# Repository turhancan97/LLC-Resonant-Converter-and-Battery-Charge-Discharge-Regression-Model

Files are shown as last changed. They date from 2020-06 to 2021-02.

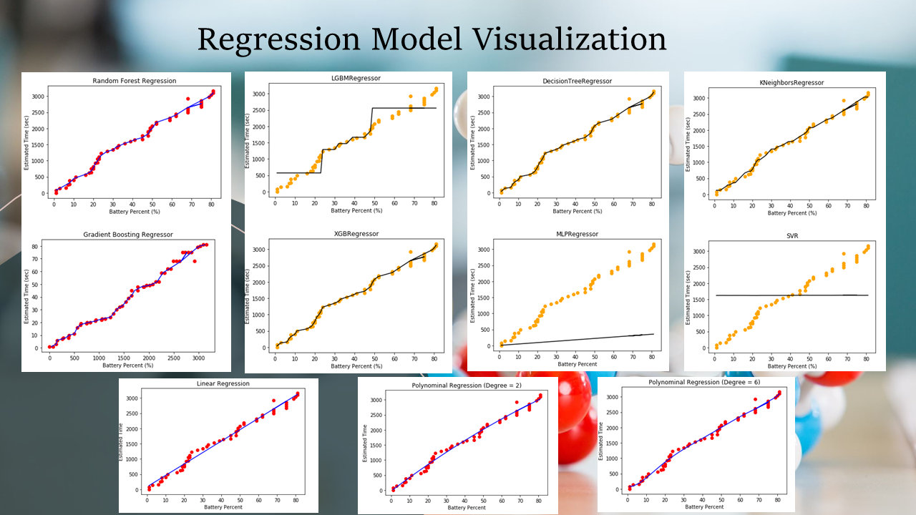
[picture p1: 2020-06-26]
Machine Learning Part/Regression Model Visualizations.png

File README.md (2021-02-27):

# High Power Efficiency Design Approach of a LLC Resonant Converter for UPS Battery Charger Application and Battery Charge - Discharge Regression Model
## Turhan Can Kargın BACHELOR OF SCIENCE GRADUATION PROJECT

In this project, an optimal design procedure of inductor-inductor-capacitor (LLC) resonant DC-DC converter is developed for uninterruptible power supply (UPS) battery charge applications based on high power efficiency. The LLC resonant converters have many advantages such as high-power efficiency and less switching losses when compared with other converters features. It is also capable of operating in narrow switching frequency where zero voltage switching can be provided. The DC-DC converter with 400V input and 48V/3.1A output has been selected as an experimental setup. In order to reach optimal design of LLC resonant converter and required output values, switching frequency might be determined as above of resonance frequency, based on theoretical calculations and Power Electronics Simulation package program. The obtained maximum power efficiency with the proposed method was measured as 95.22%. Besides, charge-discharge models of the battery were obtained from the battery data obtained via deriving regression models with machine learning algorithms where battery electrical energy consumptions, battery status, and temperature data can be analyzed. R^2 score and root mean square error tests are performed for ten different regression models. Random forest regression is determined as the best model among regression models for the obtained data set. 

Keywords: Energy; UPS battery charge; LLC resonant converter; regression models

Video -> https://www.youtube.com/watch?v=KwHaqaDpCxg&t=8s

### Simulation
Simulation_Image

### Schematic
Schematic_Image

### PCB
LLC_Demo_Board_Top

### Model Comparison
Model Comparison

### Random Forest Score After Optimization Code
Random_Forest_skorlar

### Regression Models Visualization
Regression Model Visualizations

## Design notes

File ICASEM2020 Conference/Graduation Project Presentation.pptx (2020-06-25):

## High Power Efficiency Design Approach of a LLC Resonant Converter for UPS Battery Charger Application and Battery Charge-Discharge Regression Model

Graduatıon project
Turhan Can KArgın

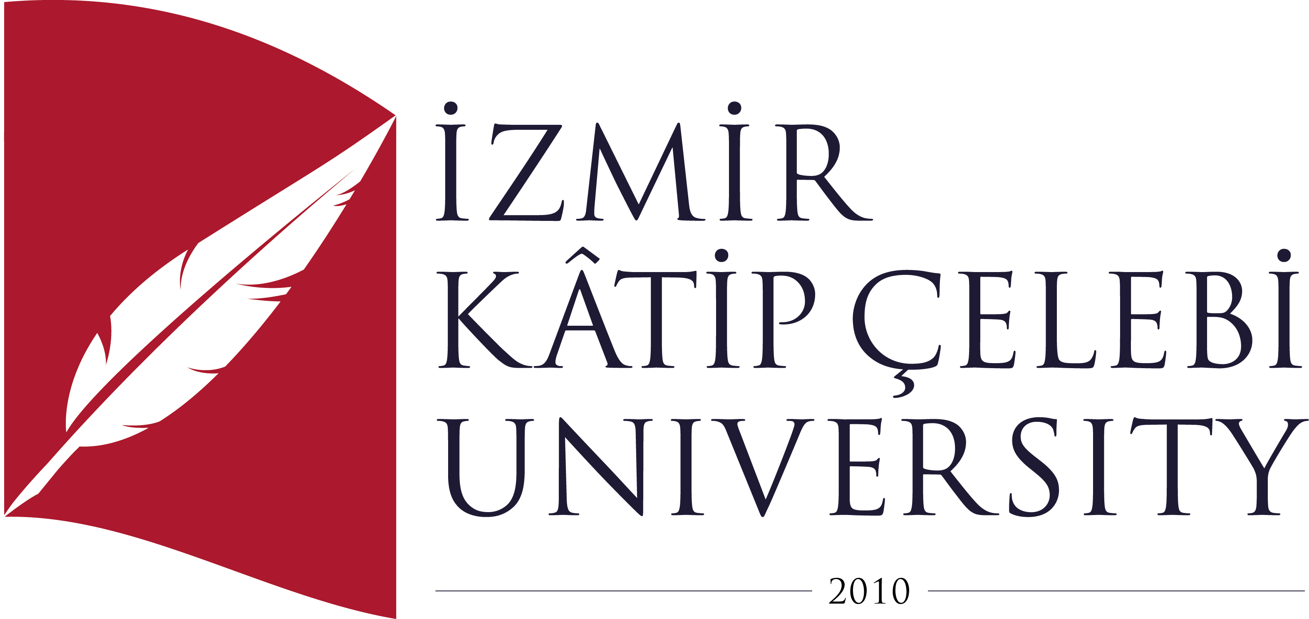
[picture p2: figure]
İzmir Kâtip Çelebi Üniversitesi - Vikipedi

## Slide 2

- SUPERVISOR: Assoc. Prof. Savaş ŞAHİN
- CO-SUPERVISOR: Fırat DEVECİ – TESCOM Elektronik A.Ş.
- This work is supported by the Scientific and Technical Research Council of Turkey (TUBITAK) under 2209B-Bachelor Final Thesis Focused on Industry Program with Project number 1139B411900874.
- This work is presented in 2nd International Conference of Applied Sciences, Engineering and Mathematics (ICASEM 2020).

High Power Efficiency Design Approach of a LLC Resonant Converter for UPS Battery Charger Application and Battery Charge-Discharge Regression Model

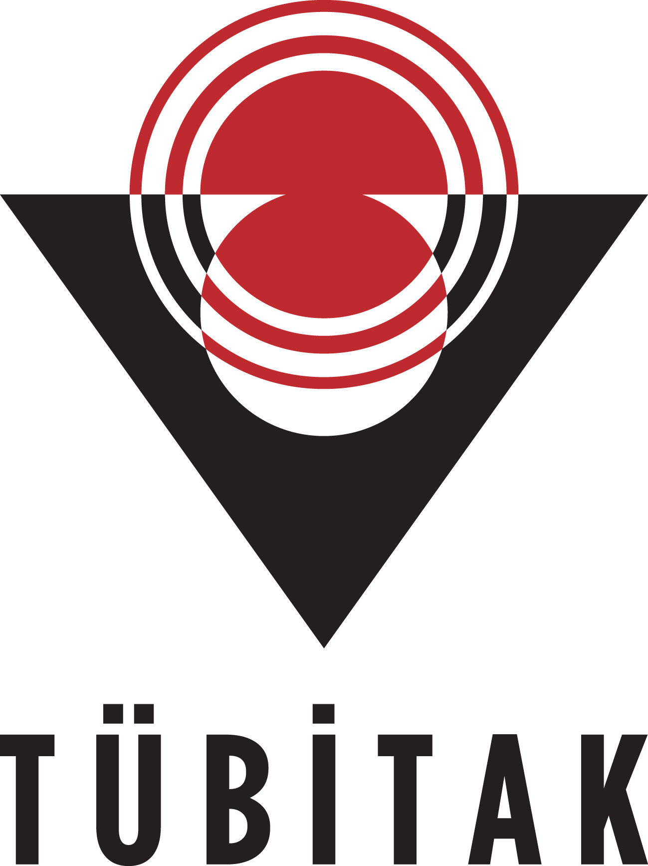
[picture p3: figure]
Tanıtım Materyalleri | BİLİŞİM ve BİLGİ GÜVENLİĞİ İLERİ ...
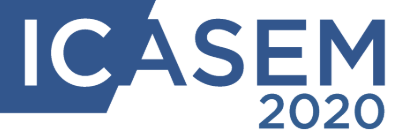
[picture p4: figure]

## Introduction

- This presentation present the analysis and design considerations for a half-bridge LLC resonant DC-DC converter. Using the fundamental approximation, the voltage and current waveforms are analyzed and the gain equations are obtained. Half-bridge LLC resonant converter has 400V input and 48V/3.1A output.The circuit is simulated using PSIM software. In addition, it is presented as secondary output to find the charge-discharge models under varying conditions by deriving the regression models with machine learning algorithms where the battery electricity energy consumption, battery status and temperature data can be analyzed.

## LLC Rezonant Converter

- 1. The advantages of LLC Rezonant Converter
- 2. Why to use as UPS Battery Charger

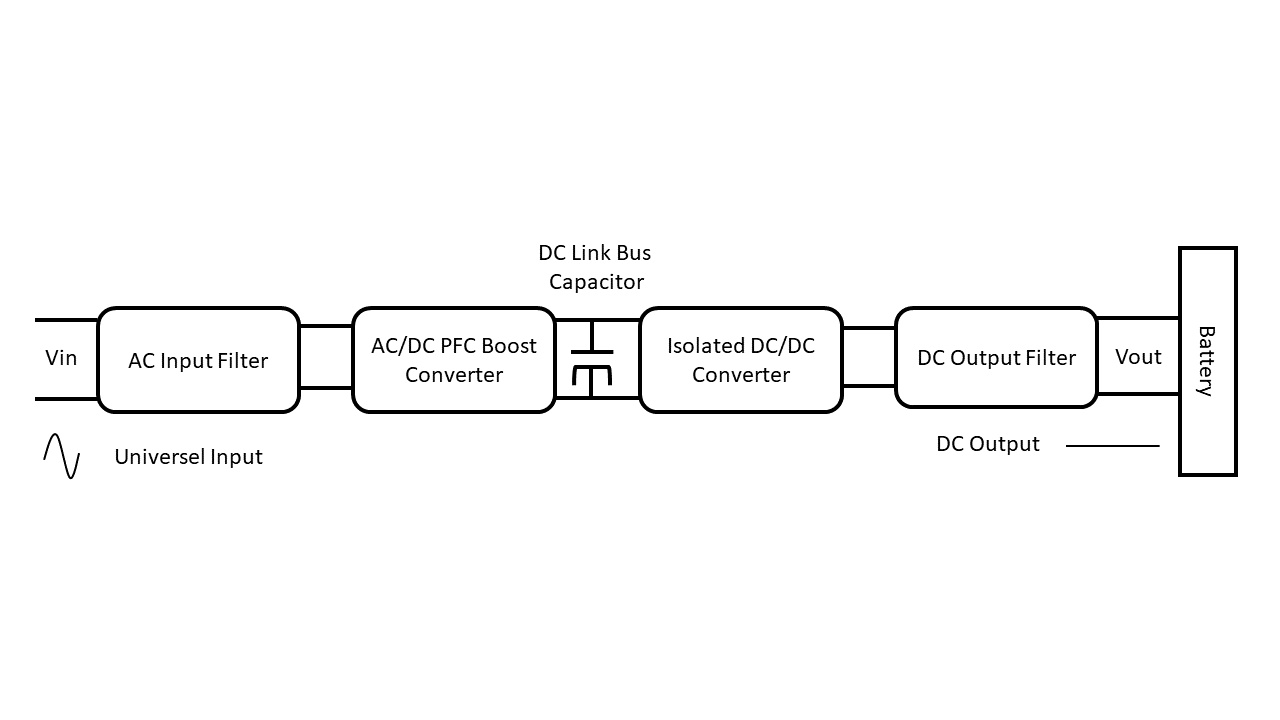
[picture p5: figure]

Block diagram of a universal battery charger

## Circuit Design

  - Define the system specifications and determine the maximum and minimum voltage gains of the resonant network
- P_(in) =(P_(out))/(E_(ff))
- V_(in)^(max) =V_(o.PFC)
- V_(in)^(max) =√(V_(O.PFC)^2 −(2P_(in) T_(HU))/(C_(DL)))
- M^(min) =√(m/(m−1))
- M^(max) = (V_(in)^(max))/(V_(in)^(min))M^(min)

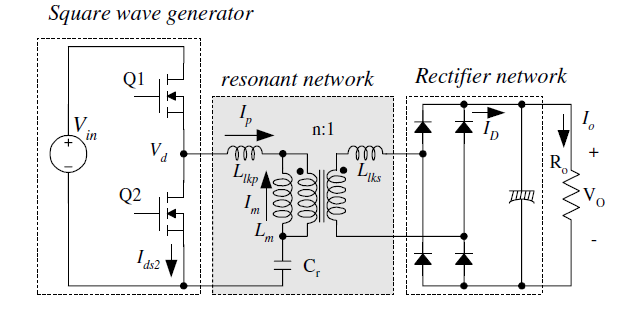
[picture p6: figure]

A schematic of half-bridge LLC resonant converter

## Circuit Design

  - Calculate the Equivalent Load Resistance and Design the resonant network
- R_(ac) = (8n^2)/(π^2)(V_0^2)/(P_0)
- C_r =1/(2πQ.f_o .R_(ac))
- L_r =1/(4π^2 f_o^2 C_r)
- L_p =m.L_r

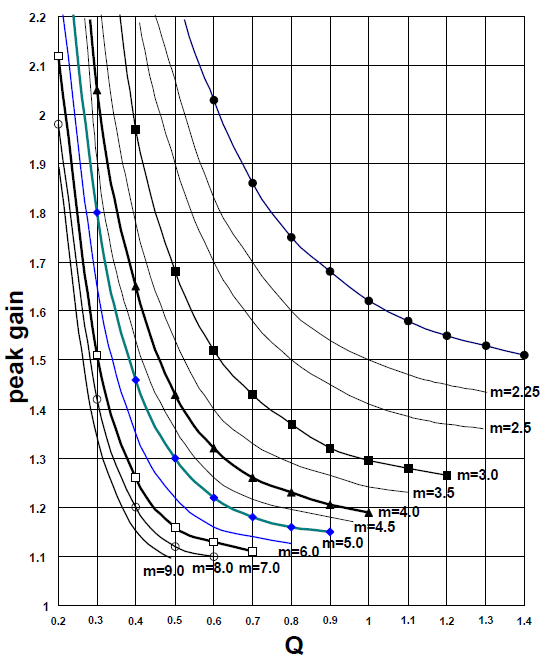
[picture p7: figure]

Peak Gain (Attainable Maximum Gain) vs. Q for Different m Values

With m value chosen in previous slide, read proper Q value from the peak gain curves in Figure that allows enough peak gain. Considering the load transient and stable zero-voltages-witching (ZVS) operation, 10~20% margin should be introduced on the maximum gain when determining the peak gain.

## Circuit Design

  - Design the transformer and select the resonant capacitor
N_p^(min) =(n(V_o +V_F ))/(2f_s^(min) ∆B.1,12.A_e)

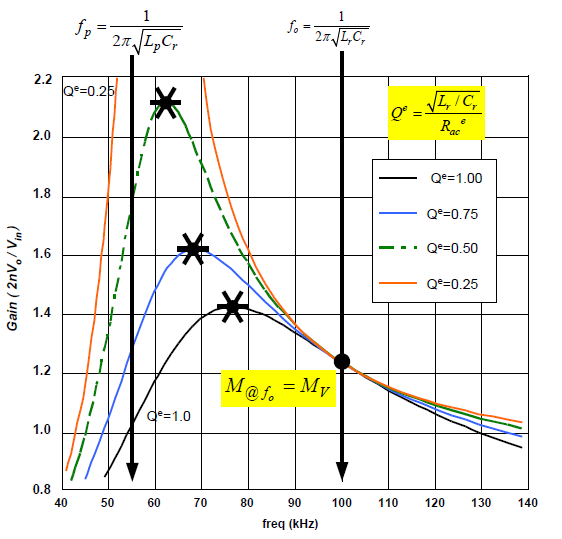
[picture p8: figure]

Typical Gain Curves of LLC Resonant Converter

From the gain curve of Figure, the minimum switching frequency will be obtained

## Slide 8

Design Specification

Define Ratio ‘n’

Design results are calculated as;
E_(ff) = %96 V_(in)^(min) = 363.276V k = 9.4
P_(in) = 150 W V_(in)^(max) = 400 V
P_(out) = 148.8W M^(min) = 1.1066
n=4.375 M^(max) = 1.22
R_(ac) = 251.9 Ω C_r = 19.03 nF
L_r = 110 uH L_p = 600 uH
L_(lkp) = 57.78 uH L_(lks) = 2.879 uF
L_m = 542.2177 uH N_p = 36
N_s = 8 I _(Cr)^(RMS) = 1.044 A
V _(Cr)^(Max) = 495 V Q = 0.302

Define Value of Mmax-Mmin

Select Value of k and Q

Check M, k and Q Graph

Are the values of M, k and Q is in the Limit.(ZVS)

NO

YES

Calculate ‘Rac’

Therotical calculation results

Calculate ‘Cr’

Circuit design results

## Simulation Results

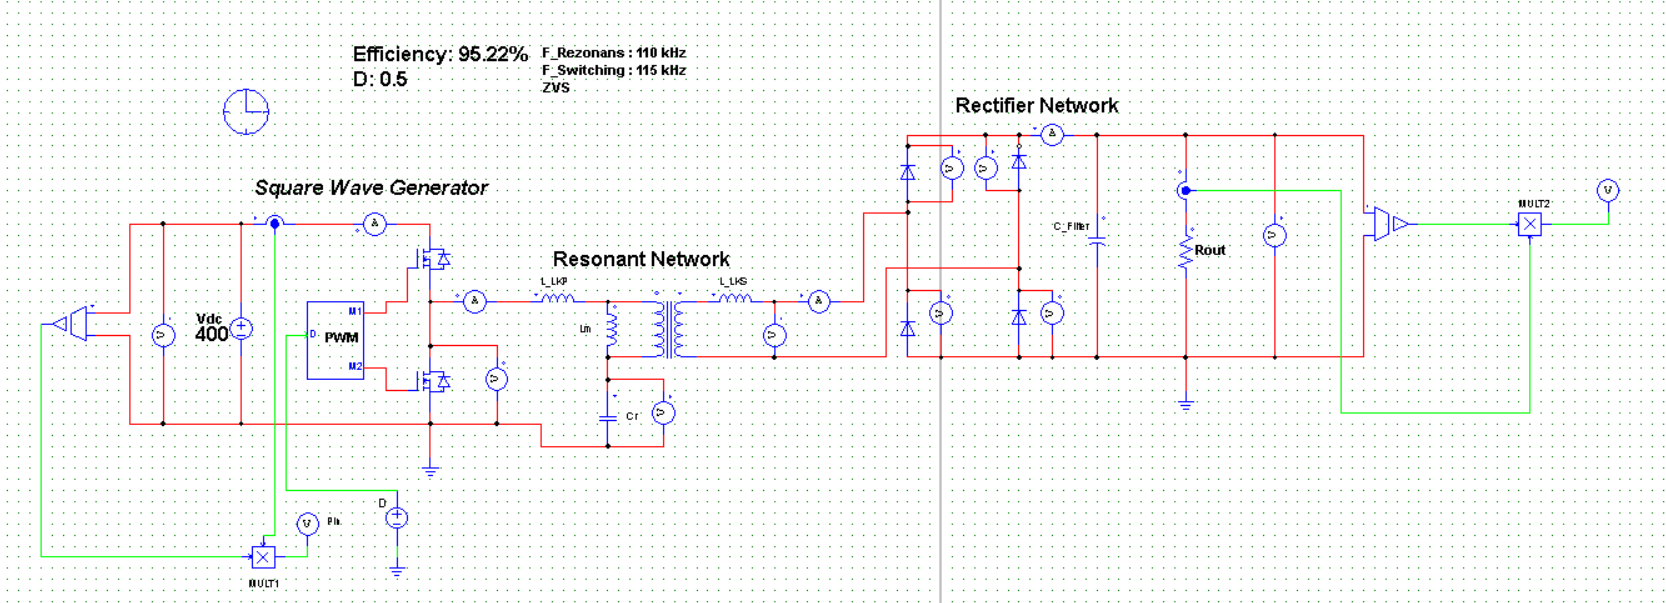
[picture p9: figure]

## Simulation Results

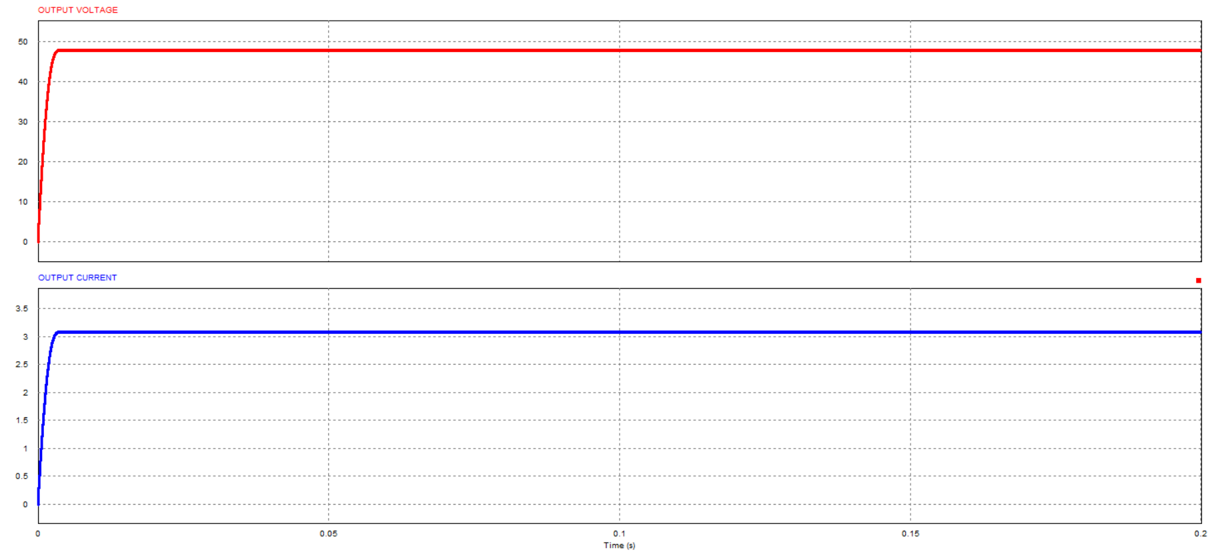
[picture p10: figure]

Output Voltage (V) and output current (A) of the LLC Resonant Converter

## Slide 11

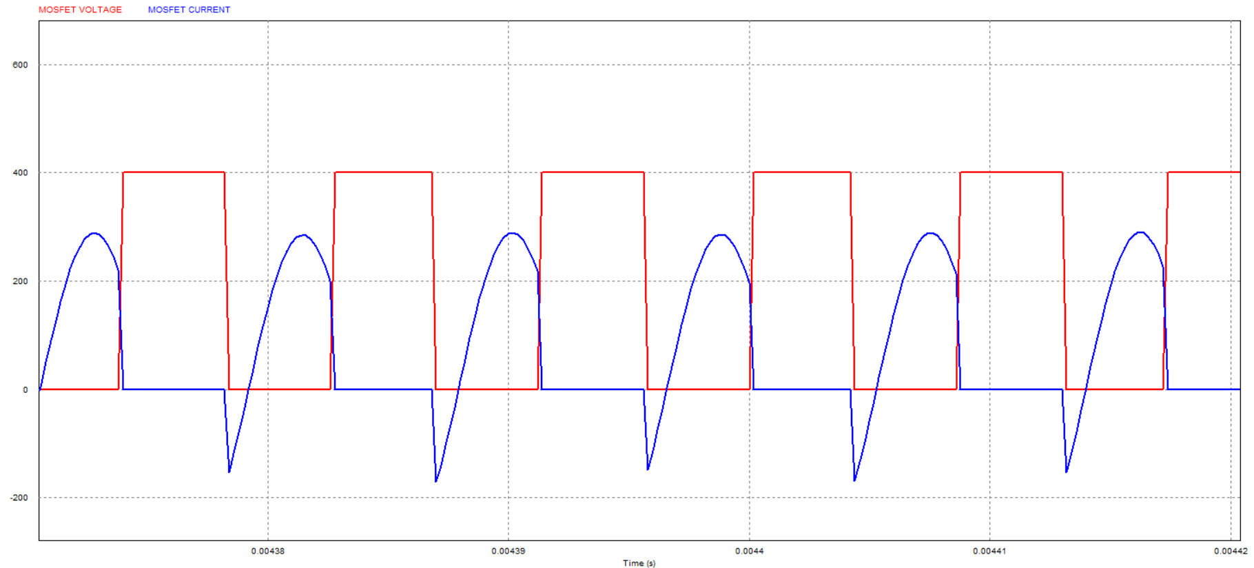
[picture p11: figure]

E_(ff) = %9 5.22

MOSFET voltage (V) and current (A) achieving soft switching

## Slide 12

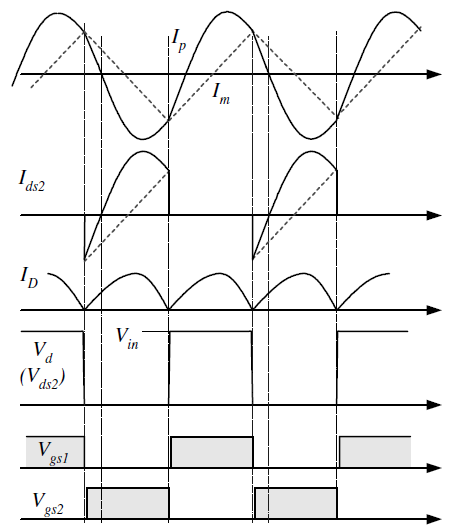
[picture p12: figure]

Typical Voltage (V) and current (A) waveforms of half-bridge LLC resonant converter

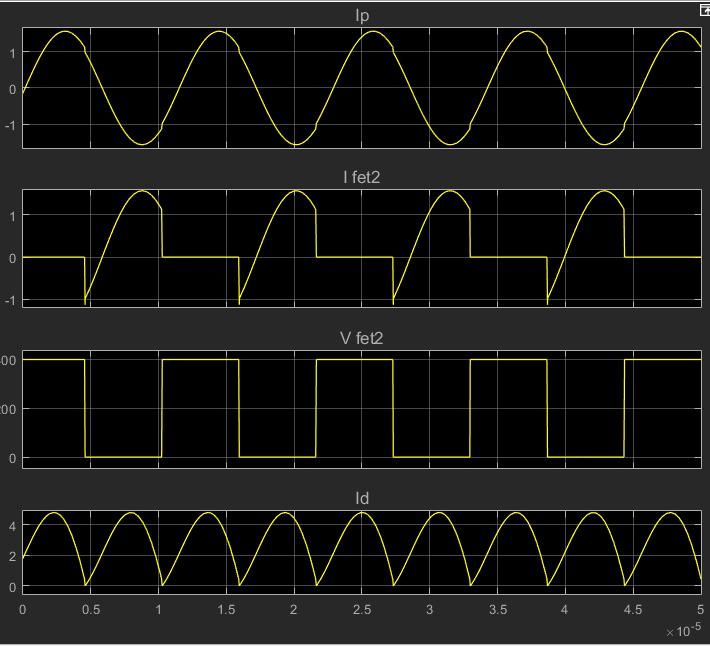
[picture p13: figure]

Simulation Voltage (V) and current (A) waveforms of resonant converter

## PCB Design

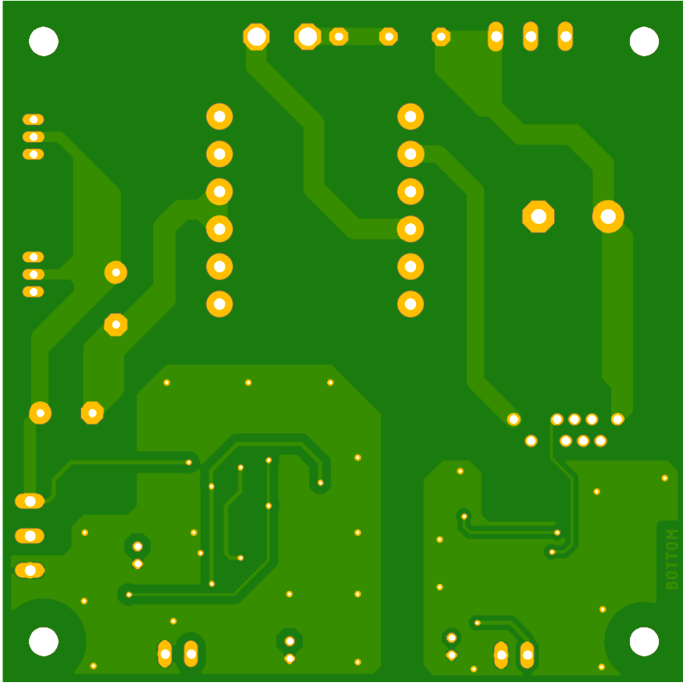
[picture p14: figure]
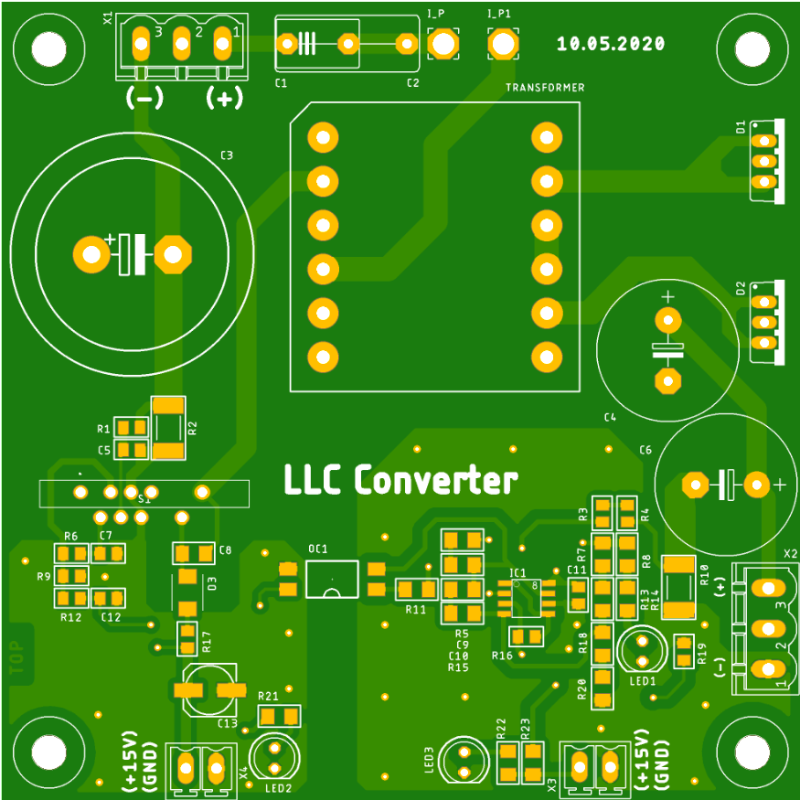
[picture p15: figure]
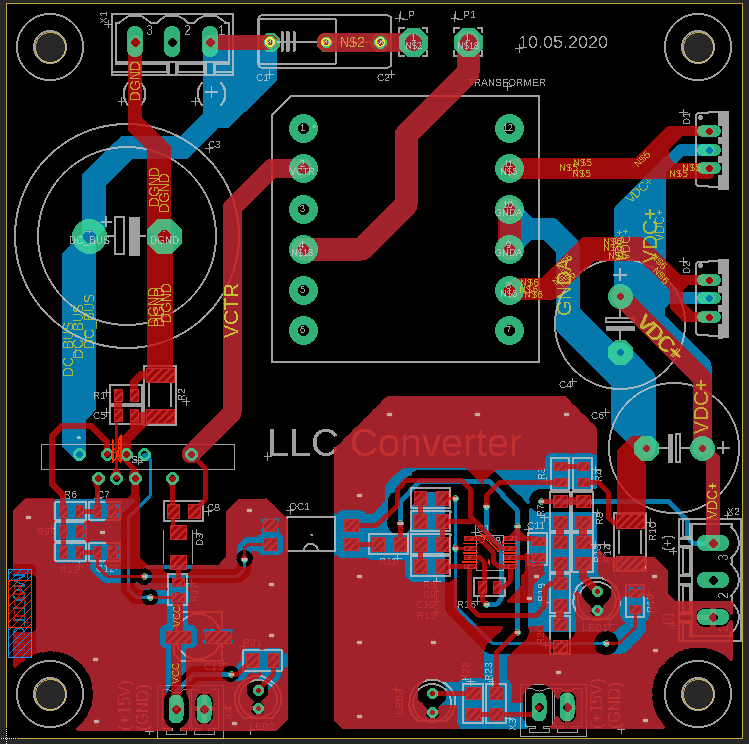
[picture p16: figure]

## Regression Models with Machine Learning

Results Regression Models | Root Mean Square Error | R^2 Score
SVR | 1057.0299 | 0.0008
Linear Regression | 77.2032 | 0.9946
LGBM Regressor | 465.0893 | 0.8065
XGB Regressor | 93.0894 | 0.9922
Gradient Boosting Regressor | 70.8098 | 0.9955
Random Forest Regressor | 67.843 | 0.9959
Decision Tree Regressor | 128.161 | 0.9853
MLP Regressor | 994.0306 | 0.1164
K-Neighbours Regressor Polynomial Regressor | 104.8204 70.5056 | 0.9901 0.9956

Regression model comparison using Python

## Regression Models with Machine Learning

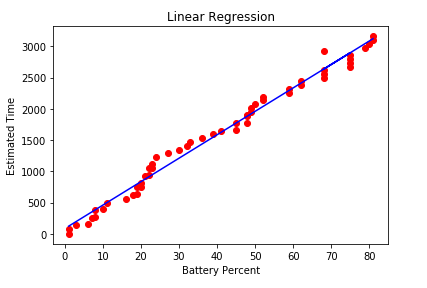
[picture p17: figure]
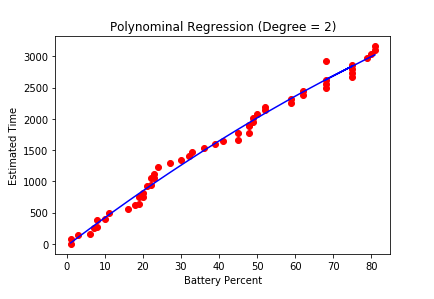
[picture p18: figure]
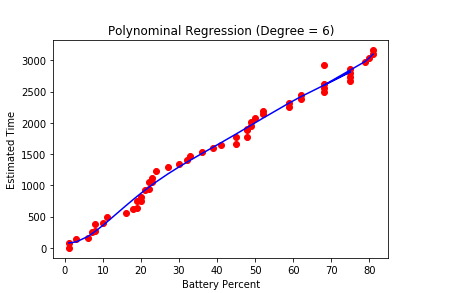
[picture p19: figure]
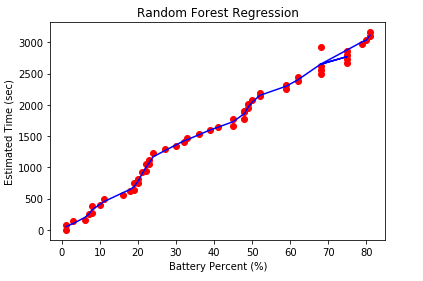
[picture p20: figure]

Visualization of battery discharge regression models

## Thank You

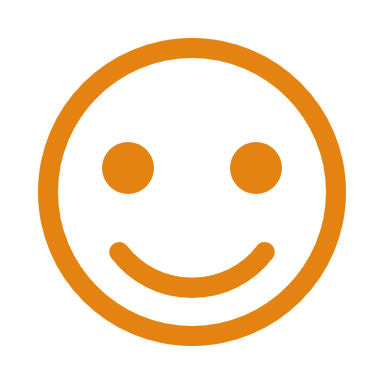
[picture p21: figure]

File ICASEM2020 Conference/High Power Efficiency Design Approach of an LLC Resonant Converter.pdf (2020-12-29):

INTERNATIONAL CONFERENCE OF APPLIED

SCIENCES, ENGINEERING AND MATHEMATICS

HIGH POWER EFFICIENCY DESIGN APPROACH OF AN LLC RESONANT CONVERTER FOR UPS BATTERY CHARGER APPLICATION AND BATTERY CHARGE-DISCHARGE REGRESSION MODEL

Turhan Can Kargın¹*

, Fırat Deveci²

, Savaş Şahin¹

1Department of Electrical and Electronics Engineering, Izmir Katip Celebi University, Izmir, Turkey
2Department of Research and Development, Tescom Elektronik A.Ş., Izmir, Turkey

Abstract - In this study, design procedure of inductor-inductor-capacitor (LLC) resonant DC-DC converter is developed for uninterruptible power supply battery charge applications based on high power efficiency. The LLC resonant converters have many advantages such as high-power efficiency and less switching losses when compared with other converters features. It is also capable of operating in narrow switching frequency where zero voltage switching can be provided. The DC-DC converter with 400V input and 48V/3.1A output has been selected as an experimental setup. In order to reach desired design of LLC resonant converter and required output values, switching frequency might be determined as above of resonance frequency via Power Electronics Simulation package program. The obtained maximum power efficiency was measured as 95.22%. Besides, charge-discharge models of the battery were obtained from the battery data obtained via deriving regression models with machine learning algorithms where battery electrical energy consumptions, battery status, and temperature data can be analyzed. R

2 and root mean square error scores are performed for different regression models. Random forest regression is determined as the best model among regression models for the obtained data set.

Key words: Energy, UPS battery charge, LLC resonant converter, machine learning, regression models

1. INTRODUCTION

Uninterruptible power supplies (UPS) are devices that provide emergency electrical power to a connected device when the input power source fails [1]. Such devices are widely used in important sectors such as industry, healthcare, and military [2-4]. The batteries used in UPS must have satisfied the features such as smooth and quick charging, high power density, high efficiency. The charging of the batteries becomes very complicated due to the high voltages and currents involved in the system and the sophisticated charging algorithms [5]. The most commonly used battery charging architecture is shown in Fig.1. It consists of mainly two stages, namely power factor correction PFC stage and DC-DC converter

2 | TURHAN CAN KARGIN, FIRAT DEVECI, SAVAŞ ŞAHIN

stage. The power factor correction stage is a continuous conduction mode of boost topology [6]. DC-DC converter plays an important role in battery charger by regulating the output current and voltage.

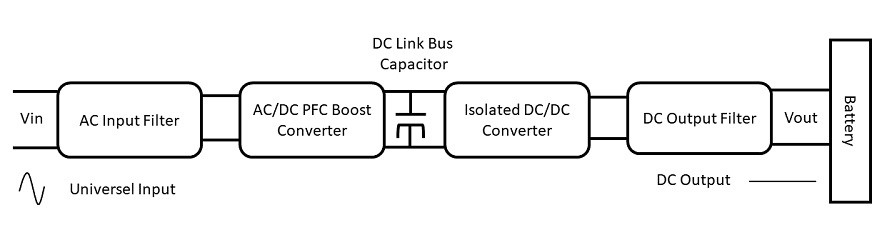
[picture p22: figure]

Fig. 1 Block diagram of a universal battery charger

It has been observed that LLC resonant converters are generally used in electrical vehicles battery charger applications because high power density and high efficiency battery chargers should be designed to have less volume and cost of electrical vehicles [7-9]. In this study, design procedure of LLC resonant converter for UPS battery charger applications based on high efficiency and battery charge-discharge regression model is aimed. In the design procedure, 4x12V UPS battery is taken into consideration. Thus, LLC resonant converter should be regulated the output voltage in a wide voltage range with different load conditions according to typical charging profile of battery. For the design procedure, basic operation characteristics of LLC resonant converter is defined, and operation regions are discussed in terms of high efficiency. To achieve high efficiency, all essential parasitic elements, including junction capacitances of all semiconductor devices and the leakage inductance and magnetizing inductance of the transformer should be utilized to achieve Zero Voltage Switching (ZVS). ZVS switching topology typically use resonance techniques to force the voltage or current in a semiconductor switch to zero, resulting to the elimination or reduction of the switching losses [10]. It is basically soft switching technique. The operation regions of LLC resonant converter are discussed to regulate wide output voltage range. Therefore, the purpose of the study is designing an LLC resonant converter that will have 48V/3.1A output values to charge 4 x 12V / 30Ah batteries. The circuit is simulated using Power Electronic Simulation Software (PSIM). In addition, it is presented as secondary output to find the charge-discharge models under varying conditions by deriving the regression models with machine learning algorithms where the battery electricity energy consumption, battery status and temperature data can be analyzed. Root mean square error (RMSE) and R

2
score tests were used to compare the obtained results.

The remaining sections are as follows; in the second section, circuit design procedure, simulation results and regression models are explained. In the third section, the results from the comparison of model performances with each other is done. In the last section, conclusions and recommendations of the study are presented.

LLC RESONANT CONVERTER FOR UPS BATTERY CHARGER APPLICATION | 3
2. MATERIALS AND METHOD

The half-bridge LLC resonant converter is given in Fig.2. The main parts of this converter are Square wave generator, Resonant network, and Rectifier network.

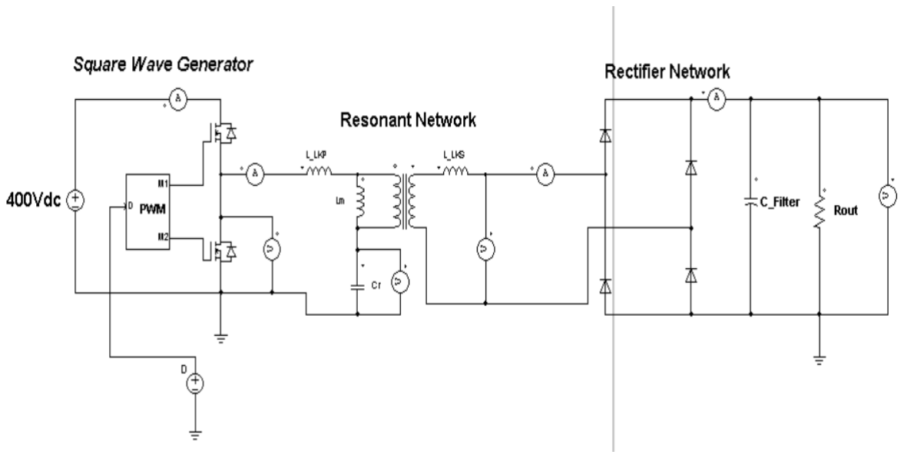
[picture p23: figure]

Fig. 2 The circuit schematic of LLC resonant DC-DC converter

The switching network produces a square wave voltage by alternating 50% duty cycle for each switch. The switching network can be full-bridge or half-bridge type. In this study, it is used as half-bridge type. The resonant network has a resonant capacitor, primary and secondary leakage inductances, and the magnetizing inductance of the transformer. The energy is transferred to the load with the help of transformers when the resonant converter allows the current to circulate. The resonant network filters the higher harmonic currents. Therefore, essentially only sinusoidal current is can flow from the resonance network, although square wave voltage is applied to the resonance network. The rectifier network consists of a filter capacitor and diodes. It produces DC voltage by rectifying the output of the transformer which is a sinusoidal voltage. This network can be full-wave bridge or center-tapped configuration [11].

2.1. Circuit Design Procedure

A dc/dc converter with 148.8W/48V output has been selected as a design for UPS battery charger. The design specifications are as follows; i) Input voltage: 400Vdc (output of PFC stage), ii) Output: 48V/3.1A (148.8W), iii) Holdup time requirement: 20ms (50Hz line freq.), and iv) DC link capacitor of PFC output: 220 µF. The design steps for the half-bridge LLC resonant converter are given below [12]. It is assumed that the efficiency is to be 0.88~0.92 for low voltage output and 0.92~0.96 for high voltage output, if its efficiency data are not provided, See Eq. (1).

o
in

ff

P
P
E
= | (1)

Mostly, LLC resonant converter operates around the resonant frequency (fo) in normal operation to attenuate switching frequency variation. The gain at fo is magnetizing inductance divided by primary side leakage inductance (k = Lm/Llkp). Therefore, the value of k should be chosen to obtain the minimum gain. Mostly, k is chosen 5~10. See Eq. (2) and Eq. (3).

1

2

min | RO | m | lkp
| max
in | m
V | L | L | k
M
V | L | k
+ | +
= | = | = | (2)

max
max | min in
min
in

V
M | M
V

=
(3)

The ratio (k) between Lm and Llkp is chosen as 9.4. LLC resonant converter contains full-

wave bridge rectifier for the rectifier network. The transformer turns ratio should be

determined for full-wave bridge rectifier. See Eq. (4).

2( 2 )

Max
p | in | min
s | o | f
N | V
n | M
N | V | V
= | =
+

(4)

Where
Vf

= 0.7V. Transformer turns ratio obtained from Eq. (4), the equivalent load

resistance is should be obtained. See Eq. (5).

2 2

2

8 | o
ac | ff o

n V
R | E
π P

=
(5)

The resonant network parameters should be determined to achieve soft switching. See Eq. (6), Eq. (7), and Eq. (8).

( | )
( | )
( | )

2
1
1
2 | 1 p | m | lkp | lkp | r

k
L | L | L | k | L | L
k

+
= | + | =
+
+ | =
(6)

( )

2

1
/ / | 1
1 | 2
r | lkp | m | lkp | lkp
o | r

k
L | L | L | L | L
k | π f | C
= | + | = | + | =
+
æ | ö ç | ÷ è | ø
(7)

1

2

r
o ac

C
πQ f R

=
- ·

(8)

The calculated parameters and magnetic component values for simulation are summarized in Table 1.

Table 1. Values used for simulation

Parameters | Values
E ff | %96
P in | 155 W
P out | 148.8 W
N | 4.375
R ac | 251.9 ohm
L r | 110 uH
L lkp | 57.78 uH
L lks | 2.879 uH
L m | 542.2177 uH
C r | 19.03 nF
L p | 600 uH
M min | 1.1066
M max | 1.22
Np : Ns | 36 : 8
Q | 0.302
K | 9.4
2.2. Simulation Results

LLC Resonant topology was built in PSIM software. The duty cycle is 0.5 and resonant frequency is 110 kHz. In order to reach desired design of LLC resonant converter and required output values, switching frequency was determined as above of resonance frequency, based on theoretical calculations and PSIM Simulation software. Therefore, the switching frequency is 115 kHz. Obtained efficiency is 95.22% and that zero voltage switching has been achieved as shown in Fig.3. The intersection area between voltage and current of MOSFET is very less.

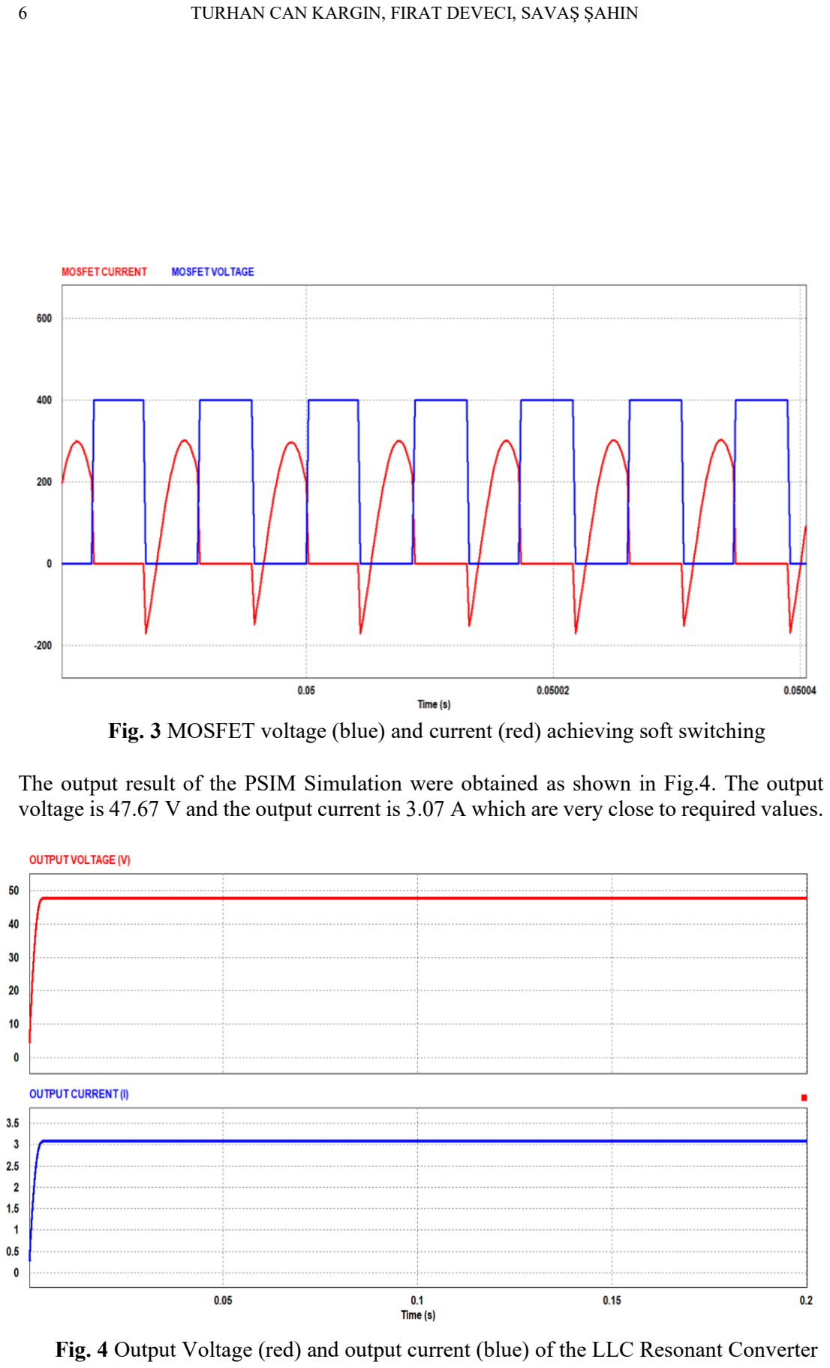
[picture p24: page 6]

Fig. 3 MOSFET voltage (blue) and current (red) achieving soft switching

The output result of the PSIM Simulation were obtained as shown in Fig.4. The output voltage is 47.67 V and the output current is 3.07 A which are very close to required values.

Fig. 4 Output Voltage (red) and output current (blue) of the LLC Resonant Converter

2.3. Regression Models

Regression analysis is a process of statistical methods which is used to estimate relationships between dependent and independent variables. The purpose of machine learning algorithms is learning to recognize the pattern with several different methods. For example, some of them are decision tree, linear regression, support vector machines, artificial neural networks, and k-nearest neighbor. Machine learning algorithms are divided into two groups: supervised learning and unsupervised learning. Regression models are in the group of supervised learning [13]. In this study, it is aimed to provide battery charge-discharge regression model to predict how long a battery with a known charge rate can be discharged according to the load and its medium temperature.by using machine learning algorithms.

3. RESULT AND DISCUSSION

Charge-discharge models of the battery is made by deriving regression models with machine learning algorithms. The data set is obtained from the 10kVA UPS produced by TESCOM A.Ş [14]. There are 4 different variables in the dataset which are discharge current, battery percentage, temperature, and battery usage time. The overall dataset was preprocessed and analyzed thoroughly. Different regression models were used to obtain battery charge-discharge regression models. These are linear, polynomial, light gradient boosting machine (LGBM), extreme gradient boosting (XGB), gradient boosting, random forest, decision tree, and K-neighbors regression. When applying these regression models, battery charge percentage and estimated time variables in the data set were used and to evaluate their performances RMSE and R

2
score are used. See Eq. (9) and See Eq. (10).

RMSE = √
∑ | (yi−ỳi
) m | 2
i=1
| m

(9)

where yi

is the time variable, ỳi
is the value of the predicted time of the regression model.

R

2 = 1− [
∑ | (yi−ỳi )
m | 2
i=1
∑ | (yi−ỹi
) m | 2
i=1
] | (10)

where yi

is the time variable, ỳi
is the value of the predicted time of the regression model and ỹi
is the is the average value of the time variable.

Finally, random forest regression model has been decided as best model among different regression models as shown in Table 2 where the lowest RMSE value and the R

2
score
value is closest to 1. It is depicted in Fig.5.

Table 2. RMSE and R

2
score values of regression models
Regression Models | RMSE | 2 Score R
Linear Regression | 77.2032 | 0.9946
Polynomial Regression | 70.5056 | 0.9956
LGBM Regression | 465.0893 | 0.8065
XGB Regression | 93.0894 | 0.9922
Gradient Boosting Reg | 70.8098 | 0.9955
Random Forest Regression | 67.843 | 0.9959
Decision Tree Regression | 128.161 | 0.9853
K-Neighbors Regression | 104.8204 | 0.9901

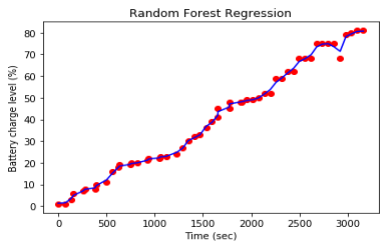
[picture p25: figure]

Fig. 5 Battery charge level versus time

4. CONCLUSION AND RECOMMENDATIONS

LLC resonant DC-DC converter was designed to achieve high efficiency in UPS battery charging applications. LLC resonant DC-DC converter was chosen because the LLC resonant converters have many advantages such as high-power efficiency, less switching losses, and operating in narrow switching frequency where zero voltage switching can be provided when compared with other converters features. Battery charge-discharge regression model is made by using machine learning algorithms, where battery status, battery electrical energy consumption and temperature data were analyzed. Root mean square error and R

2
score tests were performed for different regression models. The tests are generated in Python and the results of them are compared to each other. Random forest regression has been decided as the best regression among regression models for the obtained data set. Finally, it can be predicted how long a battery with a known charge rate can be discharged according to the load and its medium temperature. As a future work of this study could be the hardware implementation for the system and the data can be obtained from the real time application. In addition, more research can be done to make the system perform better.

Acknowledgement: This work is supported by the Scientific and Technical Research Council of Turkey (TUBITAK) under 2209B-Bachelor Final Thesis Focused on Industry Program with Project number 1139B411900874.

REFERENCES

1. A. Von Jouanne, P. Enjeti and D. Lucas, "DSP control of high power UPS systems feeding nonlinear loads," Proceedings of 1995 American Control Conference - ACC'95, Seattle, WA, USA, 1995, pp. 495-499 vol.1, doi: 10.1109/ACC.1995.529299.
2. Gu, B.; Lee, H.; Kang, C.; Sung, D.; Lee, S.; Yun, S.; Park, S.K.; Cho, G.-Y.; Kim, N.; Cha, S.W. Receding Horizon Control of Cooling Systems for Large-Size Uninterruptible Power Supply Based on a Metal-Air Battery System. Energies 2020, 13, 1611.
3. Boris N. Abramovich (2018). Uninterruptible power supply system for mining Industry enterprises. Записки Горного института, 229 (англ.) , 31-40. doi: 10.25515/PMI.2018.1.31
4. L. Zhou and Z. ping Qi, "Modeling and control of a flywheel energy storage system for uninterruptible power supply," 2009 International Conference on Sustainable Power Generation and Supply, Nanjing, 2009, pp. 1-6, doi: 10.1109/SUPERGEN.2009.5348077.
5. F. Musavi, M. Craciun, D. S. Gautam, W. Eberle and W. G. Dunford, "An LLC Resonant DC–DC Converter for Wide Output Voltage Range Battery Charging Applications," in IEEE Transactions on Power Electronics, vol. 28, no. 12, pp. 5437-5445, Dec. 2013, doi: 10.1109/TPEL.2013.2241792.
6. Sri, G., & Subbulekshmi. (2015). LLC Resonant Converter for Battery Charging Application. International Journal of Electrical Engineering, 8(4), 379–388.
7. A. Emadi, Y. J. Lee and K. Rajashekara, "Power Electronics and Motor Drives in Electric, Hybrid Electric, and Plug-In Hybrid Electric Vehicles," in IEEE Transactions on Industrial Electronics, vol. 55, no. 6, pp. 2237-2245, June 2008, doi: 10.1109/TIE.2008.922768.
8. A. Emadi, S. S. Williamson and A. Khaligh, "Power electronics intensive solutions for advanced electric, hybrid electric, and fuel cell vehicular power systems," in IEEE Transactions on Power Electronics, vol. 21, no. 3, pp. 567-577, May 2006, doi: 10.1109/TPEL.2006.872378.
9. D. S. Gautam, F. Musavi, M. Edington, W. Eberle and W. G. Dunford, "An Automotive Onboard 3.3-kW Battery Charger for PHEV Application," in IEEE Transactions on Vehicular Technology, vol. 61, no. 8, pp. 3466-3474, Oct. 2012, doi: 10.1109/TVT.2012.2210259.
10. M. M. Jovanovic, W. A. Tabisz and F. C. Lee, "Zero-voltage-switching technique in high-frequency off-line converters," APEC '88 Third Annual IEEE Applied Power Electronics Conference and Exposition, New Orleans, LA, USA, 1988, pp. 23-32, doi: 10.1109/APEC.1988.10547.
11. Junjun Deng, Siqi Li, Sideng Hu, Mi, C. C., & Ruiqing Ma. (2014). Design Methodology of LLC Resonant Converters for Electric Vehicle Battery Chargers. IEEE Transactions on Vehicular Technology, 63(4), 1581– 1592. https://doi.org/10.1109/tvt.2013.2287379
12. Choi, H. (2007). Design Considerations for an LLC Resonant Converter.
13. Ahmad, T., Chen, H., Huang, R., Yabin, G., Wang, J., Shair, J., Azeem Akram, H. M., Hassnain Mohsan, S. A., & Kazim, M. (2018). Supervised based machine learning models for short, medium and long-term energy prediction in distinct building environment. Energy, 158, 17–32. https://doi.org/10.1016/j.energy.2018.05.169
14. Tescom. (2020), [online] Available: http://www.tescom-ups.com/katalog/TR/TESCOM(TR).pdf

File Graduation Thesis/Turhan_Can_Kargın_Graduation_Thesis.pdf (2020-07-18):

## FACULTY OF ENGINEERING AND ARCHITECTURE

## ELECTRICAL AND ELECTRONICS ENGINEERING

## HIGH POWER EFFICIENCY DESIGN APPROACH OF AN

## LLC RESONANT CONVERTER FOR UPS BATTERY

## CHARGER APPLICATION AND BATTERY CHARGE -

## DISCHARGE REGRESSION MODEL

## GRADUATION PROJECT

## in partial fulfillment of the requirements for the degree of BACHELOR OF SCIENCE

## TURHAN CAN KARGIN

150403005

## SUPERVISOR: ASSOC. PROF. SAVAŞ ŞAHİN

## June 2020

i

HIGH POWER EFFICIENCY DESIGN APPROACH OF AN LLC RESONANT CONVERTER FOR UPS BATTERY CHARGER APPLICATION AND BATTERY CHARGE - DISCHARGE REGRESSION MODEL

A GRADUATION PROJECT

by

TURHAN CAN KARGIN

submitted to the ELECTRICAL AND ELECTRONICS ENGINEERING of

İZMİR KÂTİP ÇELEBİ UNIVERSITY

Approved by:

PROF. DR. ADNAN KAYA

(Signature)

Member Name (Signature) | Member Name (Signature)
Member Name (Signature) | Member Name (Signature)

JUNE 2020

ii

ABSTRACT

In this thesis, an optimal design procedure of inductor-inductor-capacitor (LLC) resonant

DC-DC converter is developed for uninterruptible power supply (UPS) battery charge

applications based on high power efficiency. The LLC resonant converters have many

advantages such as high-power efficiency and less switching losses when compared with

other converters features. It is also capable of operating in narrow switching frequency where

zero voltage switching can be provided. The DC-DC converter with 400V input and

48V/3.1A output has been selected as an experimental setup. In order to reach optimal design

of LLC resonant converter and required output values, switching frequency might be

determined as above of resonance frequency, based on theoretical calculations and Power

Electronics Simulation package program. The obtained maximum power efficiency with the

proposed method was measured as 95.22%. Besides, charge-discharge models of the battery

were obtained from the battery data obtained via deriving regression models with machine

learning algorithms where battery electrical energy consumptions, battery status, and

temperature data can be analyzed. R

2
score and root mean square error tests are performed

for ten different regression models. Random forest regression is determined as the best model

among regression models for the obtained data set.

Keywords: Energy; UPS battery charge; LLC resonant converter; regression models

iii

ÖZET

Bu tezde, yüksek güç verimliliğine dayanan kesintisiz güç kaynağı (KGK) akü şarj

uygulamaları için indüktör-indüktör-kapasitör (LLC) rezonans DA-DA dönüştürücünün

optimal tasarım prosedürü geliştirilmiştir. LLC rezonans dönüştürücülerinin yüksek güç

verimliliği ve diğer dönüştürücülerin özellikleriyle karşılaştırıldığında daha az anahtarlama

kaybı gibi birçok avantajı vardır. Ayrıca sıfır voltaj anahtarlamanın sağlanabildiği dar

anahtarlama frekansında da çalışabilir. 400V giriş ve 48V / 3.1A çıkışlı DA-DA dönüştürücü,

deneysel kurulum olarak seçilmiştir. LLC rezonans dönüştürücüsünün optimum tasarımına ve

gerekli çıkış değerlerine ulaşmak için, anahtarlama frekansı teorik hesaplamalara ve Güç

elektroniği benzetim çalışmaları paket programına dayanarak rezonans frekansının yukarısında olduğu belirlenmiştir. Önerilen yöntemle elde edilen maksimum güç verimliliği

95.22% olarak ölçülmüştür. Ayrıca, akü şarj-deşarj modelleri, akü elektrik enerjisi

tüketiminin, akü durumunun ve sıcaklık verilerinin analiz edilebildiği makine öğrenme

algoritmaları ile regresyon modelleri türetilerek elde edilen akü verilerinden elde edilmiştir.

On farklı regresyon modeli için R

2 ve hata kareler ortalamasının karesi testi yapılmıştır.

Random Forest regresyonu, elde edilen veri seti için regresyon modelleri arasında en iyi

model olarak belirlenmiştir.

Anahtar Kelimeler: Enerji; KGK akü şarjı; LLC rezonans dönüştürücü; regresyon modelleri

iv

ACKNOWLEDGMENTS

This work is supported by the Scientific and Technical Research Council of Turkey

(TUBITAK) under 2209B-Bachelor Final Thesis Focused on Industry Program with Project

number 1139B411900874.

This work is presented in 2nd International Conference of Applied Sciences, Engineering and

Mathematics (ICASEM 2020).

I would like to express my special thanks to my advisor Assoc. Prof. Savaş ŞAHİN for his

patience, motivation and continuous support. My sincere thanks also goes to Mr. Fırat

DEVECI for his guidance and helping me with every step of the project.

Finally, I would like to thank my family and friends for their endless support.

v

TABLE OF CONTENTS

vi

LIST OF TABLES

Table 3-1 Root Mean Square Error and R

vii

LIST OF FIGURES

Figure 3-5 Typical voltage and current waveforms of half-bridge LLC resonant converter ...15

Figure 3-8 Output Voltage (red) and output current (blue) of the LLC Resonant Converter ..16

Figure 3-15 Typical dc voltage gain characteristic of LLC resonant converter as function of

viii

Figure 3-30 (a) Graph of Linear Regression Model, (b) Graph of Polynomial Regression

ix

ACRONYMS

LLC Inductor-Inductor-Capacitor

SRC Series Resonant Converter

DC Direct Current

AC Alternating Current

PFC Power Factor Correction

UPS Uninterruptible Power Supply

IC Integrated Circuit

ZVS Zero Voltage Switching

PCB Printed Circuit Board

SMPS Switch Mode Power Supply

CV Constant Voltage

CC Constant Current

EMI Electromagnetic Interference

LGBM Light Gradient Boosting Machine

XGB eXtreme Gradient Boosting

MLP Multilayer Perceptron

ANN Artificial Neural Network (https://en.wikipedia.org/wiki/Artificial_neural_network)

RMSE Root Mean Square Error

### 1. INTRODUCTION

The growing demand for higher power density and low profile in power converter designs

has forced designers to increase switching frequencies. Operation at higher frequencies

considerably reduces the size of passive components such as transformers and filters.

However, switching losses have been an obstacle to high frequency operation. In order to

reduce switching losses, allowing high frequency operation, resonant switching techniques

have been developed. These techniques process power in a sinusoidal manner and the

switching devices are softly commutated. Therefore, the switching losses and noise can be

dramatically reduced. Conventional resonant converters use an inductor in series with a

capacitor as a resonant network. Two basic configurations are possible for the load

connection: series connection and parallel connections [1]. See Figure 1.1.


Figure 1-1 Half-bridge series and parallel resonant converters [1]

These two different resonant converters have some limitations. For SRC, the rectifier-load

network is placed in series with the L-C resonant network [2-4]. From this configuration, the

resonant network and the load act as a voltage divider. By changing the frequency of driving

voltage Vd, the impedance of the resonant network changes. The input voltage will be split

between this impedance and the reflected load. Since it is a voltage divider, the DC gain of an

SRC is always lower than 1. At light load condition, the impedance of the load will be very

large compared to the impedance of the resonant network; all the input voltage will be

imposed on the load. This makes it difficult to regulate the output at light load. Theoretically,

frequency should be infinite to regulate the output at no load. For parallel resonant converter,

the rectifier-load network is placed in parallel with the resonant capacitor as depicted [5-7].

Since the load is connected in parallel with the resonant network, there inevitably exists large

amount of circulating current. This makes it difficult to apply parallel resonant topologies in

high power applications. Therefore, in order to solve the limitations of the conventional resonant converters, the LLC resonant converter has been proposed. The LLC-type resonant

converter has many advantages over conventional resonant converters. First, it can regulate

the output over wide line and load variations with a relatively small variation of switching

frequency. Second, it can achieve zero voltage switching (ZVS) over the entire operating

range. Finally, all essential parasitic elements, including junction capacitances of all

semiconductor devices and the leakage inductance and magnetizing inductance of the

transformer, are utilized to achieve ZVS. See Figure 1.2.

Figure 1-2 A schematic of half-bridge LLC resonant converter [1]

Recently, the LLC resonant converter has drawn a lot of attention due to its advantages over

the conventional series resonant converter and parallel resonant converter: narrow frequency

variation over wide load and input variation and Zero Voltage Switching (ZVS) of the

switches for entire load range. The LLC-type resonant converter has many advantages over

conventional resonant converters. First, it can regulate the output over wide line and load

variations with a relatively small variation of switching frequency. Second, it can achieve

zero voltage switching (ZVS) over the entire operating range. Finally, all essential parasitic

elements, including junction capacitances of all semiconductor devices and the leakage

inductance and magnetizing inductance of the transformer, are utilized to achieve ZVS. The

battery used in Uninterruptible Power Supply should be in such a way that it should satisfy

the features such as smooth and quick charging, high power density, high efficiency.

Furthermore, battery technology is improving and as this transition occurs, the charging of

these batteries becomes very complicated due to the high voltages and currents involved in

the system and the sophisticated charging algorithms [8]. The most commonly used battery

charging architecture is shown in figure 3. It consists of mainly two stages, namely power

factor correction PFC stage and DC-DC converter stage. The power factor correction stage is

a continuous conduction mode of boost topology [9]. In this thesis, the main focus is the DC-

DC converter which plays an important role in battery charger by regulating the output

current and voltage. See Figure 1.3.


Figure 1-3 Block diagram of a universal battery charger

In this thesis, an optimal design procedure of inductor-inductor-capacitor (LLC) resonant

converter for UPS battery charger applications based on high efficiency and Battery Charge-

Discharge regression model is proposed. In the design procedure, 4x12V UPS battery is used.

Thus, LLC resonant converter should be regulated the output voltage in a wide voltage range

with different load conditions according to typical charging profile of battery. For the design

procedure, basic operation characteristics of LLC resonant converter is defined, and operation

regions are discussed in terms of high efficiency. The operation regions of LLC resonant

converter are discussed to regulate wide output voltage range. Therefore, the purpose of the

thesis is designing and producing an LLC resonant converter that will have 48V/3.1A output

values to charge 4 x 12V / 30Ah batteries. The circuit is simulated using PSIM software. PCB

design was performed by Eagle Autodesk. In addition, it is presented as secondary output to

find the charge-discharge models under varying conditions by deriving the regression models

with machine learning algorithms where the battery electricity energy consumption, battery

status and temperature data can be analyzed.

### 2. MATERIALS

### 2.1. PSIM Simulation Software

PSIM [10] is an Electronic circuit simulation software package, designed specifically for use

in power electronics and motor drive simulations but can be used to simulate any electronic

circuit. Developed by Powersim, PSIM uses nodal analysis and the trapezoidal rule

integration as the basis of its simulation algorithm. PSIM provides a schematic capture

interface and a waveform viewer Simview. PSIM has several modules that extend its

functionality into specific areas of circuit simulation and design including control theory,

electric motors, photovoltaics and wind turbines. PSIM is used by industry for research and

product development and it is used by educational institutions for research and teaching.

There are modules that enable motor drive simulation, digital control, and the calculation of

thermal losses due to switching and conduction. There is a renewable energy module which

allows for the simulation of photovoltaics (including temperature effects), batteries,

supercapacitor, and wind turbines. See Figure 2.1.

Figure 2-1 PSIM Software interface [10]

### 2.2. MATLAB Simulink

Simulink [11] is a MATLAB-based graphical programming environment for modeling,

simulating, and analyzing multidomain dynamical systems. Its primary interface is a

graphical block diagramming tool and a customizable set of block libraries. It offers tight

integration with the rest of the MATLAB environment and can either drive MATLAB or be

scripted from it. Simulink is widely used in automatic control and digital signal processing

for multidomain simulation and model-based design. See Figure 2.2.


Figure 2-2 MATLAB Simulink interface [11]

### 2.3. EAGLE Autodesk

EAGLE [12] is a scriptable electronic design automation (EDA) application with schematic

capture, printed circuit board (PCB) layout, auto-router and computer-aided manufacturing

(CAM) features. EAGLE stands for Easily Applicable Graphical Layout and is developed by

CadSoft Computer GmbH. EAGLE contains a schematic editor, for designing circuit

diagrams. Schematics are stored in files with .SCH extension, parts are defined in device

libraries with .LBR extension. Parts can be placed on many sheets and connected together

through ports. The PCB layout editor stores board files with the extension .BRD. It allows

back-annotation to the schematic and auto-routing to automatically connect traces based on

the connections defined in the schematic. In this thesis, circuit diagram and PCB designs

implemented on this program. See Figure 2.3.

Figure 2-3 EAGLE Autodesk interface [12]

### 2.4. Python and Spyder

Python [13] is an interpreted, high-level, general-purpose programming language. Python's

design philosophy emphasizes code readability with its notable use of significant whitespace.

Its language constructs and object-oriented approach aims to help programmers write clear,

logical code for small and large-scale projects. Python is dynamically typed and garbage-

collected. It supports multiple programming paradigms, including procedural, object-

oriented, and functional programming. Python is often described as a "batteries included"

language due to its comprehensive standard library.

Spyder [14] is a powerful scientific environment written in Python, for Python, and designed

by and for scientists, engineers, and data analysts. It features a unique combination of the

advanced editing, analysis, debugging and profiling functionality of a comprehensive

development tool with the data exploration, interactive execution, deep inspection, and

beautiful visualization capabilities of a scientific package. Furthermore, Spyder offers built-in

integration with many popular scientific packages, including NumPy, SciPy, Pandas,

IPython, QtConsole, Matplotlib, SymPy, and more. Beyond its many built-in features, Spyder

can be extended even further via third-party plugins. Spyder can also be used as a PyQt5

extension library, allowing you to build upon its functionality and embed its components,

such as the interactive console or advanced editor, in your own software. Python

programming language is used for the analysis of the consumption data. See Figure 2.4.


Figure 2-4 Spyder interface [14]

### 3. METHODS

### 3.1. Circuit Design

A dc/dc converter with 148.8W/48V output has been selected as a design for UPS battery

charger. The design specifications are as follows:

- Input voltage: 400Vdc (output of PFC stage)
- Output: 48V/3.1A (148.8W)
- Holdup time requirement: 20ms (50Hz line freq.)
- DC link capacitor of PFC output: 220 μF

[STEP-1] Define the system specifications

-Estimated efficiency (Eff): The power conversion efficiency must be estimated to calculate

the maximum input power with a given maximum output power. If no reference data is

available, use Eff = 0.88~0.92 for low voltage output applications and Eff = 0.92~0.96 for

high voltage output applications. See Equation 3.1

Pin =

Po

Eff

(3.1)

-Input voltage range (Vin

minand Vin

max) : Typically, it is assumed that the input voltage is

provided from Power Factor Correction (PFC) pre-regulator output. When the input voltage

is supplied from PFC output, the minimum input voltage considering the hold-up time

requirement is given. See Equation 3.2

Vin

min = √VO.PFC
2 −

2PinTHU

CDL

(3.2)

where VO.PFC is the nominal PFC output voltage, THU is a hold up time and CDL is the DC

link bulk capacitor. The maximum input voltage is given. See Equation 3.3

Vin

max = VO.PFC | (3.3)

[STEP-2] Determine the maximum and minimum voltage gains of the resonant network

It is typical to operate the LLC resonant converter around the resonant frequency (fo) in

normal operation to minimize switching frequency variation. When the input voltage is

supplied from the PFC output, the input voltage has the maximum value (nominal PFC output

voltage) in normal operation. Designing the converter to operate at fo for the maximum input

voltage condition, the minimum gain should occur at the resonant frequency (fo). The gain at

fo is a function of the ratio (k=Lm/Llkp) between the magnetizing inductance and primary

side leakage inductance. Thus, the value of k should be chosen to obtain the minimum gain.

While a higher peak gain can be obtained with a small k value, too small k value results in

poor coupling of the transformer and deteriorates the efficiency. It is typical to set k to be

5~10, which results in a gain of 1.1~1.2 at the resonant frequency (fo). With the chosen k

value, the minimum voltage gain for maximum input voltage (Vin

max) is obtained. See

Equation 3.4

Mmin =

VRO

Vin

max

2

=

Lm+Llkp
Lm

=

k+1
k

(3.4)

Then, the maximum voltage gain is given. See Equation 3.5

Mmax =

Vin

max

Vin

min . Mmin | (3.5)

The ratio (k) between Lm and Llkp is chosen as 9.4.

[STEP-3] Determine the transformer turns ratio (n=Np/Ns)

Since the full-wave bridge rectifier is used for the rectifier network, the transformer turns

ratio is given. See Equation 3.6

n =

Np
Ns

=

Vin

Max

2(Vo+2Vf)

Mmin
(3.6)

[STEP-4] Calculate the equivalent load resistance (Rac)

With the transformer turns ratio obtained, the equivalent load resistance is obtained.

See Equation 3.7

Rac =

8n

2
π²

Vo

2

Po

Eff | (3.7)

[STEP-5] Design the resonant network

With k chosen in STEP-2, read proper Q value from the peak gain curves in Figure 8 that

results in enough peak gain. 10~15% margin on the peak gain is typical. Then, the resonant

parameters are obtained. See Equation 3.8

### Lp = Lm + Llkp = (k + 1)Llkp

Lr = Llkp + Lm//Llkp = Llkp (1 +

k
k + 1

)

Cr =

1
2πQ⋅fo⋅Rac

(3.8)

Lr =

1
(2πfo)

2Cr

Lp =

(k+1)

2
(2k+1)

Lr

As calculated in STEP-2, the maximum voltage gain (Mmax) for the minimum input voltage

(Vin

min) is 1.22. With 10% margin, a peak gain of 1.5 is required. k has been chosen as 9.4 in

STEP-2 and Q is obtained as 0.302 from the peak gain curves. By selecting the resonant

frequency as 110kHz.

[STEP-6] Design the transformer

The worst case for the transformer design is the minimum switching frequency condition,

which occurs at the minimum input voltage and full load condition. To obtain the minimum

switching frequency, plot the gain curve using the gain equation and read the minimum

switching frequency. Then, the minimum number of turns for the transformer primary side is

obtained. See Equation 3.9

Np

min =

n(V0+2Vf)
2fs

min∆BAe

(3.9)

where Ae is the cross-sectional area of the transformer core in m2 and ΔB is the maximum

flux density swing in Tesla. If there is no reference data, use ΔB =0.25~0.30 T. Then, choose the proper number of turns for the secondary side that results in primary side turns larger than Np

minas given. See Equation 3.10

### Np = n . Ns > Np

min
(3.10)

Ae = 97.1 mm2 is selected for the transformer. From the gain curve in Figure 9 of the

minimum switching frequency is obtained as 85kHz.

[STEP-7] Select the resonant capacitor

When choosing the resonant capacitor, the current rating should be considered since a

considerable amount of current flows through the capacitor. The RMS current through the

resonant capacitor is given. See Equation 3.11

Icr

Rms ≅ √[
πIo
2√2n

]

2
+ [

n(Vo+2⋅Vr

)
4√2foLm

]

2
(3.11)

Then, the maximum voltage of the resonant capacitor in normal operation is given. See

Equation 3.12. See Figure 3.1.

### Vcr

max ≡

Vin

max

2

+

√2⋅Icr

RMS

2⋅π⋅f0⋅Cr

(3.12)


Figure 3-1 Peak Gain (Attainable Maximum Gain) vs. Q for Different k Values

Figure 3-2 Typical Gain Curves of LLC Resonant Converter

Following flowchart diagram was created for the design procedure and values in were

obtained as the design results. See Figure 3.2, 3.3 and 3.4.

Design Specification; Define Ratio ‘n’; Select Value of k and Q; Define Value of Mmax-Mmin; Check M, k and Q Graph; Are the values of M, k and Q is in the Limit.(ZVS); Calculate ‘Cr’; Calculate ‘Rac’; YES

Figure 3-3 Flowchart diagram for design procedure

Figure 3-4 Circuit design results

### 3.2. Simulation

After finding the theoretical results, the simulation of the converter to compare theoretical

results and simulation results was built. Typical waveforms which it has to be seen on the

simulation program. Ip is primary side leakage inductance current, Im is magnetizing current

Ids2 and Vds2are second MOSFET current and voltage and Id is rectifier side current. As you

see, the square wave generator produces a square wave voltage, Vd by driving switches, Q1

and Q2 with alternating 50% duty cycle for each switch. The square wave generator stage can

be built as a full-bridge or half bridge type. In this thesis it was used as half bridge type. See

Figure 3.5.


Figure 3-5 Typical voltage and current waveforms of half-bridge LLC resonant converter

Firstly, LLC Resonant topology was built in PSIM. The duty cycle is 0.5 and resonant

frequency is 110kHz. In order to reach optimal design of LLC resonant converter and

required output values, switching frequency was determined as above of resonance

frequency, based on theoretical calculations and PSIM Simulation software. Therefore, the

switching frequency is 115kHz. Obtained efficiency is 95.22% and that soft switching has

been achieved. The intersection area between voltage and current of MOSFET is very less.

See Figure 3.6 and 3.7

Figure 3-6 PSIM simulation design of LLC resonant DC-DC converter


Figure 3-7 MOSFET voltage (blue) and current (red) achieving soft switching

The output result of the PSIM Simulation were obtained. The output voltage is 47.67V and

the output current is 3.07A which are very close to required values. Besides, primary side

leakage inductance current, magnetizing current, rectifier side current, and MOSFETs’

voltage waveforms were obtained. Simulation results are like these typical waveforms. See

Figure 3.8, 3.9, 3.10 and 3.11.


Figure 3-8 Output Voltage (red) and output current (blue) of the LLC Resonant Converter

Figure 3-9 Magnetizing (blue) and primary side leakage inductor (red) current

Figure 3-10 Secondary side diode current (A)


Figure 3-11 First and second MOSFET voltage (V)

The RMS current through the resonant capacitor was measured as 1.072A and the maximum

voltage of the resonant capacitor in normal operation was measured as 311.5V. See Figure

3.12.

Figure 3-12 Current (black) and voltage (orange) waveforms of resonant capacitor

After that, the system was created on MATLAB Simulink. The required waveforms are

created on MATLAB Simulink too. See Figure 3.13 and 3.14.

Figure 3-13 MATLAB Simulink design of LLC resonant DC-DC converter

Figure 3-14 MATLAB Simulink design waveforms


Figure 3-15 Typical dc voltage gain characteristic of LLC resonant converter as function of load and normalized switching frequency variation [15].

In this simulations, Region 1 ZVS was decided to operate which means switching frequency

is bigger than resonant frequency. Therefore, switching frequency is selected the as 115kHz

(calculated resonant frequency is 110kHz and Q = 0.302). Typical half-bridge LLC resonant

converter waveforms should is obtained in the simulation program and the simulation results

that are similar to these typical waveforms. Besides, the simulation results of the resonant

capacitor maximum voltage and RMS current to select appropriate resonant capacitor and

according to theoretical calculation, results are very similar which means theoretical

calculations correspond to simulation results. Soft switching has been obtained succesfully.

Finally, output voltage and output current in figure 6 are 47.67V and 3.07A in simulation

which is very similar to theoretical values (48V/3.1A). In addition, simulation of LLC

resonant converter has been obtained by MATLAB Simulink to be sure that calculation is

correct, and results are almost the same. See Figure 3.15.

### 3.3. Hardware Design Part

FSFR2100XS was chosen as power unit for LLC resonant DC-DC converter and TSM1011

was chosen as control unit. See Figure 3.16 and 3.17.

Figure 3-16 Final version of the circuit without secondary side control IC


Figure 3-17 TSM1011 IC (Secondary side control unit)

The TSM1011 is a highly integrated solution for SMPS applications requiring CV (constant

voltage) and CC (constant current) modes. The voltage reference combined with one

operational amplifier makes it an ideal voltage controller. The other operational amplifier,

combined with few external resistors and the voltage reference, can be used as a current limiter [16]. For Transformer, Würt Elektronik component transformer was used. It has turn

ratio 35:8 and Input voltage is 360V to 400V, output voltage is 48V [17]. See Figure 3.18 and

3.19.

Figure 3-18 TSM1011 IC


Figure 3-19 Transformer 760895451 and properties

The FSFR-XS series includes highly integrated power switches designed for high-efficiency

half-bridge resonant converters. Offering everything necessary to build a reliable and robust

resonant converter, the FSFR- XS series simplifies designs while improving productivity and

performance. The FSFR-XS series combines power MOSFETs with fast-recovery type body

diodes, a high- side gate-drive circuit, an accurate current controlled oscillator, frequency limit circuit, soft-start, and built-in protection functions. The high-side gate-drive circuit has

common-mode noise cancellation capability, which guarantees stable operation with

excellent noise immunity. The fast-recovery body diode of the MOSFETs improves

reliability against abnormal operation conditions, while minimizing the effect of reverse

recovery. using the zero-voltage-switching (ZVS) technique dramatically reduces the

switching losses and significantly improves efficiency. The ZVS also reduces the switching

noise noticeably, which allows a small- sized Electromagnetic Interference (EMI) filter [18].

See Figure 3.20.

Figure 3-20 FSFR-XS package diagram

The design stages of the LLC resonant DC-DC converter card is made by using the Eagle

software program. Necessary electronic components were researched according to the

supplier websites (OZDISAN and DIGIKEY) provided by Tescom A.Ş. for drawing

schematic and PCB board of the circuit on Eagle. According to the components found, it was

checked whether the required footprint libraries were available in Eagle. If no suitable library

was found, appropriate footprints were drawn. There were few appropriate footprints which

must be drawn for the circuit. These footprints were drawn. For instance, the footprint of

TSM1011 control IC should have been drawn because there was no appropriate footprint

library on EAGLE. Later, the schematic of the circuit was created on Eagle Autodesk. See

Figure 3.21 and 3.22.


Figure 3-21 Primary side schematic of LLC Resonant Converter

Figure 3-22 Secondary side schematic of LLC Resonant Converter

After the schematic parts is finished, PCB design of the converter is made. The area of the

PCB has been determined as 10 cm x 10 cm. In addition, current values of all routes were

measured in the simulation program. Because the routes of the card will be made thick or thin

according to the current values. PCB composition is all about layering one material over

another. The thickest, the middle part of the board is an insulating substrate. On either side of

that is a thin layer of copper, where electric signals pass through. To insulate and protect the

copper layers, they are covered with a thin layer of lacquer-like solder mask, which is what

gives the PCB color. Finally, to top it all off, layer of ink-like silkscreen is added which can

add text and logos to the PCB. In Eagle software has function as a switch from the schematic

editor to the PCB board design. All the parts it was added from the schematic should be there,

stacked on top of each other, ready to be placed and routed. See Figure 3.23 and 3.24.

Figure 3-23 Bottom and top layer connections


Figure 3-24 PCB Board of the LLC resonant converter

### 3.4. Battery Charge – Discharge Regression Model

### 3.4.1 Data Preprocessing

Data preprocessing is the initial step to be able to apply supervised machine learning

algorithms successfully and to have better understanding of the data used. Completion of

missing data, removal of unnecessary features, data normalization, merging or removing

features that are correlated are the few examples which are commonly used for data

preprocessing [19]. Min-max normalization is one of the most common ways to normalize

data [20]. For every feature, the minimum value of that feature gets transformed into a 0, the

maximum value gets transformed into a 1, and every other value gets transformed into a

decimal between 0 and 1. See Equation 3.13.

z =

x − min(x)
max(x) − min(x)

(3.13)

### 3.4.2 Support Vector Regression

Support Vector Machines in their current form were developed at the AT&T Bell

Laboratories and gained momentum with the paper by Cortes and Vapnik (1995). Initial

applications focused on binary classification of test instances and pattern recognition. Support

Vector Machine Regression aims at finding a linear hyperplane, which fits the

multidimensional input vectors to output values. The outcome is then used to predict future

output values that are contained in a test set. Let us define a set of data points Let us define a

set of data points P = (xi

, ai), i = 1, | n witℎ xi

the input vector of data point i, ai the

actual value and n the number of data points. For linear functions f, the hyperplane that is

constructed by the SVR is determined as follows. See Equation 3.14.

f(x) = wx + b | (3.14)

Notation-wise, equation (3.14) displays similarities to a linear regression model [21].

### 3.4.3 Linear Regression

Linear regression is a statistical approach for modeling the relationship between a dependent

variable with a given set of independent variables [22]. The regression is used to identify the

strength of the effect that the independent variable(s) have on a dependent variable. Also, it

provides to understand how much the dependent variable changes with a change in one or

more independent variables. In a simple linear regression model, a single response

measurement Y is related to a single regressor X for each observation. The assumption of the

model is that the conditional mean function is linear. See Equation 3.15.

Y = α0 + α1x1 | (3.15)

In most problems, more than one predictor variable is available [23]. This leads to the

following multiple regression mean function. See Equation 3.16.

Y = α0 + α1x1 + α2x2+ | +αixi | (3.16)

where Y is the predicted output, xn (n=1,2,3,…,i) are the features, βn (n=0,1,2,…,i) are the

constant parameters determined in the training phase of the model. βn coefficients are most

important parameter for predict output variable accurately.

### 3.4.4 LightGBM Regression

LightGBM [24] is a gradient boosting framework that uses tree-based learning algorithms.

There are several advantages. These are better accuracy, lower memory usage and faster

training speed and higher efficiency etc.

### 3.4.5 XGB Regression

XGBoost (https://xgboost.ai/) [25] is a decision-tree-based ensemble machine learning algorithm that uses

a gradient boosting (https://en.wikipedia.org/wiki/Gradient_boosting) framework. In prediction problems involving unstructured data artificial

neural networks tend to outperform all other algorithms or frameworks. However, when it

comes to small-to-medium structured/tabular data, decision tree based algorithms are

considered best-in-class right now.

### 3.4.6 Gradient Boosting Regression

Gradient boosting is a machine learning (https://en.wikipedia.org/wiki/Machine_learning) technique for regression (https://en.wikipedia.org/wiki/Regression_(machine_learning)) and classification (https://en.wikipedia.org/wiki/Classification_(machine_learning)) problems,

which produces a prediction model in the form of an ensemble (https://en.wikipedia.org/wiki/Ensemble_learning) of weak prediction models,

typically decision trees (https://en.wikipedia.org/wiki/Decision_tree_learning) [26]. It builds the model in a stage-wise fashion like

other boosting (https://en.wikipedia.org/wiki/Boosting_(machine_learning)) methods do, and it generalizes them by allowing optimization of an

arbitrary differentiable (https://en.wikipedia.org/wiki/Differentiable_function) loss function. (https://en.wikipedia.org/wiki/Loss_function)

### 3.4.7 Random Forest Regression

Random forest is similar to decision tree in that samples are drawn to construct multiple

trees; the difference is that the each tree is grown with a randomized subset of predictors,

hence the name ‘‘random’’ forests. A large number of trees (500 to 2,000) are grown, hence a

‘‘forest’’ of trees. The number of predictors used to find the best split at each node is a

randomly chosen subset of the total number of predictors. The number of predictors used to

find the best split at each node is a randomly chosen subset of the total number of predictors.

The trees are grown to maximum size without pruning, and aggregation is by averaging the

trees [27]. Out of-bag samples can be used to calculate an unbiased error rate and variable

importance, eliminating the need for a test set or cross-validation. Because a large number of

trees are grown, there is limited generalization error which means that no overfitting is

possible, a very useful feature for prediction.

### 3.4.8 Decision Tree Regression

Decision Trees are a non-parametric supervised learning method used for classification and

regression [28]. The goal is to create a model that predicts the value of a target variable by

learning simple decision rules inferred from the data features. Decision trees are commonly

used in operations research, specifically in decision analysis, to help identify a strategy most

likely to reach a goal, but are also a popular tool in machine learning.

### 3.4.9 MLP Regressor

A multilayer perceptron (MLP) is a class of feedforward (https://en.wikipedia.org/wiki/Feedforward_neural_network) artificial neural network (https://en.wikipedia.org/wiki/Artificial_neural_network) (ANN).

The term MLP is used ambiguously, sometimes loosely to any feedforward ANN, sometimes

strictly to refer to networks composed of multiple layers of perceptron [29]. An MLP consists

of at least three layers of nodes: an input layer, a hidden layer and an output layer [30].

Except for the input nodes, each node is a neuron that uses a nonlinear activation function. (https://en.wikipedia.org/wiki/Activation_function)

MLP utilizes a supervised learning (https://en.wikipedia.org/wiki/Supervised_learning) technique called backpropagation (https://en.wikipedia.org/wiki/Backpropagation) for training.

### 3.4.10 K-Neighbors Regression

In pattern | recognition, (https://en.wikipedia.org/wiki/Pattern_recognition) | the k-nearest | neighbors | algorithm (k-NN) | [31] | is | a non-

parametric (https://en.wikipedia.org/wiki/Non-parametric_statistics) method used for classification (https://en.wikipedia.org/wiki/Statistical_classification) and regression (https://en.wikipedia.org/wiki/Regression_analysis) In both cases, the input consists of

the k closest training examples in the feature space. (https://en.wikipedia.org/wiki/Feature_space) K-NN is a type of instance-based

learning or lazy learning, where the function is only approximated locally and all

computation is deferred until function evaluation. Both for classification and regression, a

useful technique can be to assign weights to the contributions of the neighbors, so that the

nearer neighbors contribute more to the average than the more distant ones.

### 3.4.11 Error Metrics

In an accurate and reliable regression model, the aim is that there is no difference between the

actual observation value and the estimated value or the difference is minimum. Various

numerical measure methods are developed for this. Coefficient of determination (R2) is a

numerical measure of some type of correlation, meaning a statistical relationship between

two variables [32]. See Equation 3.17

| | R

2 = 1 − [
∑ | (yi−ỳi
| | | | )
m | 2
i=1
∑ | (yi−ỹi
) m | 2
i=1
] | (3.17)

Root Mean Square Error (RMSE) is the standard deviation of the residuals prediction errors

[33]. Residuals are a measure of how far from the regression line data points are; RMSE is a

measure of how spread out these residuals are. In other words, it tells you how concentrated

the data is around the line of best fit. Root mean square error is commonly used in

climatology, forecasting, and regression analysis to verify experimental results. See Equation

3.18.

RMSE = √
∑ | (yi−ỳi
) m | 2
i=1
| m

(3.18)

### 3.4.12 Dataset and Regression Models Results

Firstly, the dataset was obtained from TESCOM A.Ş. batteries. There are 4 different

variables in the dataset which are discharge current, battery percentage, indoor temperature

and Time. See Figure 3.25.


Figure 3-25 The dataset obtained from TESCOM A.Ş.

Next, the data set was tried with 10 different regression models in Python. Root Mean Square

error and R2 Score comparison of the models and result were obtained. See Figure 3.26, See

Table 3.1.

Table 3-1: Root Mean Square Error and R

2 Score Values of Regression Models

Results Regression Models | Root Mean Square Error | 2 R Score
SVR | 1057.0299 | 0.0008
Linear Regression | 77.2032 | 0.9946
LGBM Regressor | 465.0893 | 0.8065
XGB Regressor | 93.0894 | 0.9922
Polynomial Regressor | 70.5056 | 0.9956
Gradient Boosting Regressor | 70.8098 | 0.9955
Random Forest Regression | 67.843 | 0.9959
Decision Tree Regression | 128.161 | 0.9853
MLP Regression | 994.0306 | 0.1164
K-Neighbours Regressor | 104.8204 | 0.9901

Finally, Random Forest has been decided as best model among 10 different regression

models. After that, optimization and importance of variables algorithm was built. Originally,

Random Forest regression model had 67.843 Root mean square error and 0.9959 R

2
score.

After applying optimization algorithm, it has 55.4131 Root mean square error and 0.9973 R

2
score. See Figure 3.27, 3.28 and 3.29.


Figure 3-26 Regression models comparison code

Figure 3-27 Optimization code

Figure 3-28 Importance of variables code


Figure 3-29 Importance of variables result

Later, model visualization code was built. As shown in the images, we have proved that

Linear Regression, Polynomial Regression, Gradient Boosting Regression, Random Forest

Regression, and XGB Regression are more successful models. Models were modeled to show

how long the battery can be discharged according to the battery's charge rate. The conclusion

we will draw from these images gives polynomial regression closer estimates than linear

regression. When we compare polynomial degrees, six predicts better results than two

degrees. However, this does not mean that as the degree increases, it always gives better

results. It will be overfitting. According to the algorithm, 6 degrees gives the most ideal

result. Finally, the reason why these models were created is to be able to predict how long a

battery with a known charge rate can be discharged according to the load and its medium

temperature. See Figure 3.30(a), 3.30(b), 3.30(c), 3.30(d), 3.31, 3.32, 3.33, 3.34, 3.35, 3.36,

3.347, 3.38, 3.39, and 3.40.

(a)

(b)

(c)

Figure 3-30 (a) Graph of Linear Regression Model, (b) Graph of Polynomial Regression

Model (Degree = 2), (c) Graph of Polynomial Regression Model (Degree = 6)

Figure 3-31 Graph of Random Forest Regression Model


Figure 3-32 Graph of Gradient Boosting Regression Model

Figure 3-33 Graph of LightGBM Regression Model


Figure 3-34 Graph of XGB Regression Model


Figure 3-35 Graph of Decision Tree Regression Model

Figure 3-36 Graph of MLP Regression Model


Figure 3-37 Graph of K-Neighbors Regression Model

Figure 3-38 Graph of Support Vector Regression Model


Figure 3-39 Model visualization code for linear and polynomial regression models


Figure 3-40 Model visualization code for other regression models

### 4. SUMMARY AND CONCLUSION

In the proposed thesis, LLC resonant DC-DC converter was designed to achieve high

efficiency in UPS battery charging applications. LLC resonant DC-DC converter was chosen

because the LLC resonant converters have many advantages such as high-power efficiency,

less switching losses, and operating in narrow switching frequency where zero voltage

switching can be provided when compared with other converters features. The 48V-30Ah

battery is charged with a prototype that operates with 48 V constant output voltage and 3.1A

constant current output parameters with the design approach to be obtained. Besides, battery

charge-discharge regression model is made by using machine learning algorithms, where

battery status, battery electrical energy consumption and temperature data were analyzed.

Root mean square error and R

2
score tests were performed for different regression models are

generated in Python and the results of them are compared to each other. Random forest

regression has been decided as the best regression among regression models for the obtained

data set.

As a result, 95.22% power efficiency is achieved by the simulation program PSIM and

battery unit of UPS in Tescom A.Ş. can be charged with high efficiency. Besides, it can be

predicted how long a battery with a known charge rate can be discharged according to the

load and its medium temperature.

REFERENCES

[1] Design Considerations for an LLC Resonant Converter Hangseok Choi Fairchild

Semiconductor 82-3, Dodang dong, Wonmi-gu Bucheon-si, Gyeonggi-do, Korea

[2] A. F. Witulski and R. W. Erickson, “Design of the series resonant converter for

minimum stress,”

[3] R. Oruganti, J. Yang, and F.C. Lee, “Implementation of Optimal Trajectory Control of

Series Resonant Converters,”.

[4] V. Vorperian and S. Cuk, “A Complete DC Analysis of the Series Resonant Converter,”
[5] Y. G. Kang, A. K. Upadhyay, D. L. Stephens, “Analysis and design of a half-bridge

parallel resonant converter operating above resonance,”

[6] R. Oruganti, J. Yang, and F.C. Lee, “State Plane Analysis of Parallel Resonant

Converters,”

[7] M. Emsermann, “An Approximate Steady State and Small Signal Analysis of the

Parallel Resonant Converter Running Above Resonance,”

[8] An LLC Resonant DC–DC Converter for Wide Output Voltage Range Battery Charging

Applications Fariborz Musavi, Senior Member, IEEE, Marian Craciun, Member, IEEE,

Deepak S. Gautam, Student Member, IEEE, Wilson Eberle, Member, IEEE, and

William G. Dunford, Senior Member, IEEE

[9] LLC Resonant Converter for Battery Charging Application G. Subitha Sri and Dr. D.

Subbulekshmi School of Electrical Engineering, VIT University, Chennai Associate

professor, School of Electrical Engineering, VIT University, Chennai

[10] PSIM (Online) https://powersimtech.com/products/psim/
[11] MATLAB Simulink (Online) https://www.mathworks.com/products/simulink.html
[12] Eagle (Online) https://www.autodesk.com/products/eagle/overview
[13] Python (Online) https://www.python.org
[14] Spyder (Online) https://anaconda.org/anaconda/spyder
[15] High efficiency design approach of a LLC resonant converter for on-board electrical vehicle battery charge applications Sevilay ÇETİN

[16] TSM1011 https://www.st.com/en/power-management/tsm1011.html
[17] Transformer https://www.we-online.com/
[18] FSFR2100XS | https://www.onsemi.com/products/power-management/ac-dc-

controllers-regulators/offline-regulators/fsfr2100xs (https://www.onsemi.com/products/power-management/ac-dc-controllers-regulators/offline-regulators/fsfr2100xs)

[19] Elmaz, F., Yücel, Ö., & Mutlu, Evaluating the Effect of Blending Ratio on the Co-

Gasification of High Ash Coal and Biomass in a Fluidized Bed Gasifier Using Machine

Learning. Mugla Journal of Science and Technology, 5(1), 1-12.

[20] Patro, S., & Sahu, K. K. (2015). Normalization: A preprocessing stage. arXiv preprint

arXiv:1503.06462.

[21] Support Vector Machine Regression for project control forecasting Mathieu Wautersa ,

Mario Vanhoucke

[22] Seber, George AF, and Alan J. Lee (2012). Linear regression analysis. Vol. 329. John

Wiley & Sons

[23]Myers, R. H., & Myers, R. H. (1990). Classical and modern regression with

applications (Vol. 2). Belmont, CA: Duxbury press.

[24] LGBM Regression (Online) https://lightgbm.readthedocs.io/en/latest/
[25] XGB Regression (Online) https://machinelearningmastery.com
[26] Breiman, L. (June 1997). "Arcing The Edge" (https://statistics.berkeley.edu/sites/default/files/tech-reports/486.pdf) . Technical Report 486. Statistics

Department, University of California, Berkeley.

[27] Pal, M. (2005). Random forest classifier for remote sensing classification. International

Journal of Remote Sensing, 26(1), 217-222

[28] Kamiński, B.; Jakubczyk, M.; Szufel, P. (2017). "A framework for sensitivity analysis

of decision trees". (https://www.ncbi.nlm.nih.gov/pmc/articles/PMC5767274) Central European Journal of Operations Research. 26 (1): 135–159.

[29] Hastie, Trevor. Tibshirani, Robert. Friedman, Jerome. The Elements of Statistical

Learning: Data Mining, Inference, and Prediction. Springer, New York, NY, 2009.

[30] Rumelhart, David E., Geoffrey E. Hinton, and R. J. Williams. "Learning Internal

Representations by Error Propagation". (https://apps.dtic.mil/dtic/tr/fulltext/u2/a164453.pdf) David E. Rumelhart, James L. McClelland, and

the PDP research group. (editors), Parallel distributed processing: Explorations in the

microstructure of cognition, Volume 1: Foundation. MIT Press, 1986

[31] Altman, Naomi S. (https://en.wikipedia.org/wiki/Naomi_Altman) (1992). "An introduction to kernel and nearest-neighbor

nonparametric regression" (https://ecommons.cornell.edu/bitstream/1813/31637/1/BU-1065-MA.pdf) The American Statistician. 46 (3): 175–185.

[32] Nagelkerke, Nico JD. "A note on a general definition of the coefficient of

determination." Biometrika 78.3 (1991): 691-692.

[33] Willmott, C. J., & Matsuura, K. (2005). Advantages of the mean absolute error (MAE)

over the root mean square error (RMSE) in assessing average model performance.

Climate research, 30(1), 79-82.

PERSONAL INFORMATION Turhan Can Kargın

Abdulhamid Yavuz Caddesi - Atifbey Mahallesi - No:31 Daire:3 Kat :3 - Gaziemir,

35410 Izmir (Turkey)

+905455291939

turhancan.kargin@gmail.com

https://www.linkedin.com/in/turhancankargin/ https://turhancankargin.wordpress.com/

Skype live:turhancans97

Sex Male | Date of birth 11/11/1997 | Nationality Turkish

EDUCATION AND TRAINING

09/2015–Present | Bachelor of Science (BSc), Electrical and Electronics Engineering
| Izmir Katip Celebi University, Izmir (Turkey)
| http://www.ikc.edu.tr/ (http://www.ikc.edu.tr/#_blank)
| ▪ Intensive Intermediate English Coursework (2015-2016)
| ▪ Cumulative GPA: 3.6/4
| Elective Courses
1) Power Electronics
2) Industrial Automation
3) Process Control and Instrumentation
4) Introduction to Machine Learning
5) Presentation Techniques
6) FPGA
09/2016–Present | Business Administration
| Anadolu University, Eskisehir (Turkey)
| www.anadolu.edu.tr/acikogretim (http://www.anadolu.edu.tr/acikogretim#_blank)
| Faculty of Open University
| Cumulative GPA: 2.71/4

17/02/2019–06/07/2019 | Erasmus+ (Exchange) Program
| Poznan University of Technology, Poznan (Poland)
| https://www.put.poznan.pl/en/erasmus/erasmus-incoming-students
| ▪ I have attended the Erasmus+ Exchange Program, which allows the undergraduate students to
| take varied courses about their majors at different universities for a half year in Europe.
| Courses:
1) Computer Networks
2) Optical Fiber Comm. Systems
3) Telecommunication Networks
4) Digital Signal Processing
5) Polish
| ▪ Semester Average Grade : 4.53/5

WORK EXPERIENCE

18/06/2018–13/07/2018 | Production Intern
| Tescom Elektronik San. ve Tic. A.Ş., İzmir (Turkey)
| http://www.tescom-ups.com/ (http://www.tescom-ups.com/#_blank)
| ▪ I was a production intern at Tescom UPS. I have worked on different sections of the manufacturing:
| PCB Typesetting, Card Test, Cabling and Device Test
| ▪ Power Electronics
| ▪ Uninterruptible Power Supplies
| Business or sector Uninterruptible Power Supply
05/08/2019–05/09/2019 | Office Intern
| ELPRO Enerji Sanayi ve Ticaret Limited Şirketi, İzmir (Turkey)
| http://www.elpro.com.tr/ (http://www.elpro.com.tr/#_blank)
- Structure Electrical Installation Design
- AutoCad

Business or sector Electrical

03/07/2017–28/07/2017 | Optional Intern
| Maselmak Mühendislik, Ankara (Türkiye)
| http://maselmak.com.tr/ (http://maselmak.com.tr/#_blank)
- Electrical Panel Design (See Electrical)
- Tia Portal
- PLC

Business or sector Automation

16/12/2019–Present | Part-Time Working Student Engineer
| Grup ASM Endüstriyel Motor, Izmir (Turkey)
| http://grup-ex.com/ (http://grup-ex.com/#_blank)
| ▪ Ex-Proof Products
| Business or sector Industrial Motor, Automotive, Machinery

PERSONAL SKILLS

Mother tongue(s) | Turkish
Foreign language(s) | UNDERSTANDING | SPEAKING | WRITING
| Listening | Reading | Spoken interaction | Spoken production
English | C1 | C1 | C1 | C1 | C1

Certificate of Attendance from Turkish-American Association

German | B1 | B1 | B1 | B1 | B1
| | | Das Akademie
Polish | A1 | A1 | A1 | A1

Polish Language Course for Foreigners

Communication skills | ▪ Strong communication skills.
| ▪ Open-minded,
| ▪ Tolerant
| ▪ Good Listener
| ▪ Open to Criticism
Organisational / managerial skills | ▪ IEEE IKCU Board Member (Treasurer) (400+ Members)
| ▪ IEEE IKCU Power and Energy Society Vice Chairman (Community with 50 active members)
Job-related skills | ▪ To be able to produce solutions quickly
| ▪ Team work predisposition
Digital skills | SELF-ASSESSMENT

Information

processing

Communicati

on

Content

creation

Safety

Problem-

solving

Proficient user | Independent user | Basic user | Basic user | Proficient user

Digital skills - Self-assessment grid (http://europass.cedefop.europa.eu/en/resources/digital-competences)

- Proteus Isis/Ares
- NI Multisim
- MATLAB
- Google SketchUp
- Arduino
- C Programming Language
- Microsoft Office Powerpoint/Excel/Word
- AutoCAD
- WireShark
- SoMachine
- ABB Automation Builder

- Power Electronics (DC-DC Converters)
- Eagle Autodesk
- PSIM
- Labview
- Python
- Machine Learning
- PIC Programming
- Raspberry Pi
- FPGA (VHDL)
Other skills | ▪ Guitar
| ▪ Sport
| ▪ Football
| ▪ Fishing
| ▪ Basketball
| ▪ Photography
| ▪ Barista
| ▪ Travel Lover:
| Greece,Macedonia,Serbia,Hungary,Austria,Slovakia,Czechia,Germany,Holland,Belgium,France,S
| pain,Italy,Slovenia,Croatia,Bulgaria,Ukraine,Georgia,Bosnia Herzegovina,Montenegro,Albania,K
| osovo.Poland,Sweden,Denmark,Portugal,Morocco,Norway
Driving licence | B

ADDITIONAL INFORMATION

Projects | ▪ Basic Uninterruptible Power Supply (2018)
| We have designed basic UPS for Electronics-2 Lecture with my group.
| ▪ Smart Traffic Light (2017)
| Smart Traffic Light with logic gates has been designed for Logic Design Lecture with my group.
| ▪ High Power Efficiency Design Approach of an LLC Resonant Converter for UPS Battery Charger
| Application and Battery Charge-Discharge Regression Model (2020- Graduation Project)
| The purpose of the project is to design and produce an LLC resonant converter that will have
| 48V/3.1A output values to charge 4 x 12 V / 30 Ah batteries and obtaining a charge-discharge
| regression model of battery with machine learning algorithms.
| ▪ Climate Change: Prediction of Future Temperature (2019)
| In this project, we used machine learning algorithms to see the rising of the average temperature in
| the Earth. We can predict the future average temperature for countries and besides, we can see the
| decline of the ice extent of north and south poles.
| ▪ OPC Server Based DC Motor Control with PLC Communication System (2019)
| In this project, dc motor control was performed between NI Labview 2019 and ABB PM564 type
| PLC by using the OPC server.
| ▪ Controlling AC Motor Speed and Direction by Using PLC and STM32F4 Microcontroller with
| Matlab Graphical User Interface (2019)
| MATLAB GUI is designed to make serial bi-directional communication with STM32
| microcontroller and a uni-directional communication is made between PLC and STM32
| microcontroller. After the connections, information from external sensors from other devices is used
| to drive AC Motor with the help of PLC.
| ▪ Erbium-Doped Fiber Amplifier (2019)
| Optical Fiber Comm. Systems Lecture project.

Certifications | ▪ Machine Learning with Python Udemy Certificate of Completion
| ▪ PCB Design with Autodesk Eagle Udemy Certificate of Completion
| ▪ The 3D Printing Revolution by University of Illinois (Coursera)
| ▪ 3D Printing Applications by University of Illinois (Coursera)
| ▪ Turkcell Arduino 101 Certificate of Achievement
| ▪ Turkcell Python 101 - 201 - 301 - 401 Certificate of Achievement
| ▪ Turkcell Data Visualization Certificate of Achievement
| ▪ Turkcell Data Manipulation 101 - 201 Certificate of Achievement
| ▪ Turkcell Statistics for Data Science 101 - 201 Certificate of Achievement
| ▪ Turkcell Data Pre-Processing Certificate of Achievement
| ▪ Turkcell Introduction to Data Science and Artificial Intelligence
| ▪ Turkcell Data Literacy Certificate of Achievement
| ▪ Turkcell Machine Learning 101 - 201 - 301 - 401 - 501 Certificate of Achievement
| ▪ Turkcell Big Data with Python Certificate of Achievement
| ▪ Turkcell Data Science Project Cycle Certificate of Achievement
| ▪ IZMIR-TAA C2 Level English Certificate of Attendance
| ▪ Polish Language Course Certificate for Foreigners
| ▪ Das Akademie B1.1 Level German Certificate
| ▪ KOSGEB Entrepreneurship Training Certificate of Participation
| ▪ ICASEM 2020 CERTIFICATE OF PARTICIPATION
Memberships | ▪ The Chamber of Electrical Engineers (EMO) for Students
| ▪ IEEE Global Member
| ▪ IEEE PES Global Member
| ▪ IEEE Izmir Katip Celebi University
References | ▪ Assoc. Prof. Savas Sahin
| Department of Electrical And Electronics Engineering at Izmir Katip Celebi University /
| savas.sahin@ikcu.edu.tr

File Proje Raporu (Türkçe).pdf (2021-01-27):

# ÜNÜ

2209-B

## SANAYİYE YÖNELİK LİSANS ARAŞTIRMA PROJELERİ DESTEKLEME PROGRAMI

## SONUÇ RAPORU

PROJE | BAŞLIĞI: | Kesintisiz | Güç | Kaynakları | Akü | Şarj

## Uygulamaları için Yüksek Güç Verimli bir LLC Rezonanslı DA-DA Dönüştürücünün Tasarımı ve Akü Şarj-Deşarj Regresyon Modeli

## PROJE YÜRÜTÜCÜSÜNÜN ADI: Turhan Can KARGIN

## AKADEMİK DANIŞMANININ ADI: Doç. Dr. Savaş ŞAHİN

## SANAYİ DANIŞMANININ ADI: Müh. Fırat DEVECİ

## GENEL BİLGİLER

PROJENİN KONUSU | Kesintisiz Güç Kaynakları Akü Şarj Uygulamaları için Yüksek Güç Verimli bir LLC Rezonanslı DA-DA Dönüştürücünün Tasarımı ve Akü Şarj-Deşarj Regresyon Modeli
PROJE YÜRÜTÜCÜSÜNÜN ADI | Turhan Can KARGIN
DANIŞMANIN ADI | Doç. Dr. Savaş ŞAHİN
PROJE BAŞLANGIÇ VE BİTİŞ TARİHLERİ | 01.10.2019 – 26.06.2020

## 1. Giriş

Güç dönüştürücü tasarımlarında artan güç yoğunluğu ve düşük profiller için artan talep, tasarımcıları anahtarlama frekanslarını artırmaya zorladı. Daha yüksek frekanslarda çalışma, transformatörler ve filtreler gibi pasif bileşenlerin boyutunu önemli ölçüde azaltır. Ancak, anahtarlama kayıpları yüksek frekanslı çalışma için bir engel olmuştur. Yüksek frekanslı çalışmaya izin veren anahtarlama kayıplarını azaltmak için rezonans anahtarlama teknikleri geliştirilmiştir. Bu teknikler gücü sinüzoidal bir şekilde işler ve anahtarlama cihazları yumuşak bir şekilde değiştirilir. Bu nedenle, anahtarlama kayıpları ve gürültü önemli ölçüde azaltılabilir. Geleneksel rezonans dönüştürücüler, rezonans ağı olarak kapasiteli seri bir indüktör kullanır [1]. Yük bağlantısı için iki temel konfigürasyon mümkündür. Bunlar seri bağlantı ve paralel bağlantılardır (Şekil 1.1).


Şekil 1.1 Yarım köprü geleneksel seri ve paralel rezonans dönüştürücüler [1]

Bu iki farklı rezonans dönüştürücünün bazı sınırlamaları vardır. Doğrultucu yükü ağı, seri bağlantı için L-C rezonans ağı ile seri olarak yerleştirilir [2-4]. Bu konfigürasyondan görüldüğü gibi, rezonans ağı ve yük bir voltaj bölücü görevi görür. Vd sürüş voltajının frekansını değiştirerek, rezonans ağının empedansı değişir. Giriş voltajı bu empedans ve yansıyan yük arasında bölünecektir. Bir voltaj bölücü olduğundan, seri bağlantının DC kazancı her zaman 1'den düşüktür. Hafif yük koşulunda, yükün empedansı, rezonans ağın empedansına kıyasla çok büyük olacaktır; tüm giriş gerilimi yüke uygulanmış olur. Bu, hafif yükte çıkışın düzenlenmesini zorlaştırır. Teorik olarak, yükü yüksüz olarak düzenlemek için frekans sonsuz olmalıdır. Paralel rezonans dönüştürücü için doğrultucu yükü ağı, gösterildiği gibi rezonans kapasiteye paralel olarak yerleştirilir [5-7]. Yük rezonans ağına paralel bağlandığından, kaçınılmaz olarak büyük miktarda sirkülasyon akımı vardır. Bu, yüksek güçlü uygulamalarda paralel rezonans topolojilerinin uygulanmasını zorlaştırır. Bu nedenle, geleneksel rezonans dönüştürücülerin sınırlamalarını çözmek için indüktör-indüktör-kapasitör (LLC) rezonans dönüştürücüsü önerilmiştir (Şekil 1.2). LLC tipi rezonans dönüştürücünün geleneksel rezonans dönüştürücülere göre birçok avantajı vardır. İlk olarak, çıkışı geniş hat ve yük varyasyonları üzerinde nispeten küçük bir anahtarlama frekansı varyasyonu ile düzenleyebilir. İkincisi, tüm çalışma aralığında sıfır voltaj anahtarlaması (ZVS) elde edebilir. Son olarak, ZVS'yi elde etmek için tüm yarı iletken cihazların birleşme kapasiteleri ve transformatörün kaçak endüktansı ve mıknatıslanma endüktansı dahil olmak üzere tüm temel parazit elemanları kullanılır.

Şekil 1.2 Yarım köprü LLC rezonans dönüştürücünün şeması [1]

Son zamanlarda, LLC rezonans dönüştürücü, geleneksel seri rezonans dönüştürücü ve paralel rezonans dönüştürücüye göre avantajları nedeniyle çok dikkat çekti: geniş yük ve giriş varyasyonunda dar frekans değişimi ve tüm yük aralığı için ZVS çalışması LLC tipi rezonans dönüştürücünün geleneksel rezonans dönüştürücülere göre birçok avantajı vardır. İlk olarak, çıkışı geniş hat ve yük varyasyonları üzerinde nispeten küçük bir anahtarlama frekansı varyasyonu ile düzenleyebilir. İkincisi, tüm çalışma aralığında ZVS elde edebilir. Son olarak, ZVS'yi elde etmek için tüm yarı iletken cihazların birleşme kapasiteleri ve transformatörün kaçak endüktansı ve mıknatıslanma endüktansı dahil olmak üzere tüm temel parazit elemanları kullanılır. Kesintisiz Güç Kaynağında kullanılan pil, düzgün ve hızlı şarj, yüksek güç yoğunluğu, yüksek verimlilik gibi özellikleri karşılayacak şekilde olmalıdır. Ayrıca, pil teknolojisi gelişiyor ve bu geçiş gerçekleştikçe, bu pillerin şarj edilmesi, sistemdeki yüksek voltaj ve akımlar ve gelişmiş şarj algoritmaları nedeniyle çok karmaşık hale geliyor [8]. En yaygın olarak kullanılan pil şarj mimarisi Şekil 1.3’te gösterilmektedir. Temel olarak PFC aşaması ve DA-DA dönüştürücü aşaması olmak üzere iki aşamadan oluşur. Güç faktörü düzeltme aşaması, takviye topolojisinin sürekli iletim modudur [9]. Bu çalışmada ana odak, çıkış akımını ve voltajını düzenleyerek akü şarj cihazında önemli bir rol oynayan DA-DA dönüştürücüsüdür.


Şekil 1.3 Evrensel akü şarj cihazının blok şeması

Bu çalışmada, yüksek verimliliğe dayanan kesintisiz güç kaynakları akü şarj uygulamaları için LLC rezonans dönüştürücüsünün optimal tasarım prosedürü ve akü şarj-deşarj regresyon modeli önerilmektedir. Tasarım prosedüründe 4x12V UPS aküsü kullanılmıştır. Bu nedenle, LLC rezonans dönüştürücü, akünün tipik şarj profiline göre farklı yük koşullarında geniş bir voltaj aralığında çıkış voltajını ayarlamalıdır. Tasarım prosedürü için LLC rezonans dönüştürücüsünün temel çalışma özellikleri tanımlanmış ve çalışma bölgeleri yüksek verimlilik açısından tartışılmıştır. LLC rezonans dönüştürücüsünün çalışma bölgeleri, geniş çıkış voltaj aralığını düzenlemek için tartışılmıştır. Bu nedenle, çalışmanın amacı 4 x 12V / 30Ah pilleri şarj etmek için 48V / 3.1A sabit çıkış değerlerine sahip bir LLC rezonans dönüştürücü tasarlamak ve üretmektir. Devre PSIM yazılımı kullanılarak benzetim çalışmaları gerçekleştirilmiştir. PCB tasarımı Eagle Autodesk programı tarafından gerçekleştirilmiştir. Ayrıca, regresyon modellerinin akü elektrik enerjisi tüketimi, akü durumu ve sıcaklık verilerinin analiz edilebildiği makine öğrenme algoritmaları ile türetilerek şarj-deşarj modellerinin farklı koşullar altında bulunması ikincil çıktı olarak sunulmuştur.

## 2. Rapor dönemlerinde yapılan çalışmalar

### 2.1 Devre Tasarımı

Kesintisiz güç kaynakları akü şarj cihazı için tasarım olarak 148.8W / 48V çıkışlı bir DA-DA dönüştürücü seçilmiştir. Tasarım özellikleri aşağıdaki gibidir:

- Giriş gerilimi: 400Vdc (PFC aşamasının çıkışı)
- Çıkış değerleri: 48V/3.1A (148.8W)
- Bekleme süresi gereksinimi: 20ms (50Hz hat frekansı)
- PFC çıkış DA bara kapasitesi: 220 uF

[ADIM-1] Sistem teknik özelliklerinin tanımlanması:

İlk adım olarak, aşağıdaki özellik tanımlanmalıdır.
Tahmini verimlilik (Eff): Verilen maksimum çıkış gücü ile maksimum giriş gücünü hesaplamak için güç dönüşüm verimliliği tahmin edilmelidir. Referans verisi mevcut değilse, düşük voltaj çıkışlı uygulamalar için Eff = 0.88 ~ 0.92 kullanılır ve yüksek gerilim çıkışlı uygulamalar için Eff = 0.92 ~ 0.96 kullanılır. Giriş gücü denklem 1’de verildiği gibidir.

Pin =

Po

Eff

(Denklem 1)

Giriş Gerilimi Aralığı (Vin

minand Vin

max): Sıklıkla, giriş geriliminin PFC’den sağlandığı varsayılır. Giriş voltajı PFC çıkışından beslendiğinde, minimum giriş voltajı bekleme süresi şartı dikkate alındığında minimum giriş gerilimi denklem 2’de verildiği gibidir.

Vin

min = √VO.PFC
2 −

2PinTHU

CDL

(Denklem 2)

VO.PFC nominal PFC çıkış gerilimidir. THU bekleme süresidir ve CDL ise DA bulk bara kondansatörüdür. Maksimum giriş gerilimi denklem 3’te verildiği gibidir.

Vin

max = VO.PFC | (Denklem 3)

[ADIM-2] Rezonans ağının maksimum ve minimum gerilim kazançlarının belirlenmesi:

LLC rezonans dönüştürücünün normal çalıştırmada anahtarlama değişimini en aza indirmek için rezonans frekansı (fo) etrafında çalıştırılması sıklıkla başvurulan bir durumdur. Giriş voltajı PFC çıkışından beslendiğinde, giriş voltajı normal çalışmada maksimum değere (nominal PFC çıkış gerilimi) sahiptir. Dönüştürücüyü maksimum giriş gerilimi koşulu için rezonans frekansında çalıştırmak için rezonans frekansında minimum kazanç olmalıdır. Rezonans frekansındaki kazanç, mıknatıslanma endüktansı ile birincil kaçak endüktansı arasındaki oranın bir fonksiyonudur (k=Lm/Llkp). Bu nedenle, k değeri asgari kazancı elde etmek için seçilmelidir. Daha yüksek bir tepe kazancı küçük bir k değeri ile elde edilirken, çok küçük k değeri, düşük trafo bağlantısına ve verimliliğinin bozulmasına neden olur. Sıklıkla k değerinin 5 ~ 10 olarak ayarlanması tercih edilir. Bu da rezonans frekansında 1.1 ~ 1.2 civarı bir kazanç ile sonuçlanır. Seçilen k değeri ile, minimum gerilim kazancı maksimum giriş gerilimi denklem 4’te verildiği gibi elde edilir.

Mmin =

VRO
Vin

max

2

=

Lm+Llkp
Lm

=

k+1
k

(Denklem 4)

Ardından, maksimum gerilim kazancı denklem 5’te verildiği gibidir.

Mmax =

Vin

max

Vin

min . Mmin | (Denklem 5)

Lm ve Llkp arasındaki oran (k) 9.4 olarak seçilmiştir.

[ADIM-3] Trafo sarım oranını belirleme (n = Np / Ns):

Doğrultucu ağ için tam dalga köprü doğrultucu kullanıldığından, trafo sarım oranı denklem 6’da verildiği gibidir.

n =

Np
Ns

=

Vin

Max

2(Vo+2Vf)

Mmin
(Denklem 6)

[ADIM-4] Eşdeğer yük direncinin hesaplanması (Rac):

Denklem 6'dan elde edilen transformatör dönüş oranı ile, eşdeğer yük direnci denklem 7’de verildiği şekilde elde edilir.

Rac =

8n

2
π²

Vo

2

Po

Eff | (Denklem 7)

[ADIM-5] Rezonans ağını tasarımı:

İkinci adımda seçilen k değeri ile, Q değeri yeterli tepe noktası kazanımı sağlayan tepe kazanç eğrisinden (Şekil 2.1) düzgünce okunulmalıdır. 10 ~ 15% tepe kazancındaki pay normal bir durumdur. Ardından, rezonans parametreleri denklem 8’de verildiği gibi elde edilir.

Lp = Lm + Llkp = (k + 1)Llkp

Lr = Llkp + Lm//Llkp = Llkp (1 +

k
k + 1

)

Cr =

1
2πQ⋅fo⋅Rac

(Denklem 8)

Lr =

1
(2πfo)

2Cr

Lp =

(k+1)

2

(2k+1)

Lr

Minimum giriş gerilimi için maksimum gerilim kazancı 1.22'dir. % 10'luk marj ile 1,5'lik bir tepe kazancı gerekir. İkinci adımda k 9.4 olarak seçildi ve Q, tepe kazanç eğrilerinden 0.302 olarak elde edildi. Rezonans frekansını 110kHz olarak seçildi.

Şekil 2.1 Farklı k değerleri için Tepe Kazanç (Ulaşılabilir Maksimum Kazanç) vs. Q

[ADIM-6] Trafo tasarımı:

Transformatör tasarımı için en kötü durum minimum giriş gerilimi ve tam yük durumunda meydana gelen minimum anahtarlama frekansı koşuludur. Trafonun minimum birincil sarım sayısı denklem 9’de verildiği gibidir.

Np

min =

n(V0+2Vf)
2fs

min∆BAe

(Denklem 9)

Ae transformatör çekirdeğinin kesit alanıdır (m2) ve ΔB maksimum akı yoğunluğu salınımıdır (Tesla). Eğer referans verisi yok, ΔB = 0.25 ~ 0.30 T kullanılır. Ardından, ikincil taraf için uygun sarım sayısını denklem 10’da verildiği şekilde seçmeliyiz.

Np = n . Ns > Np

min
(Denklem 10)

Transformatör için Ae = 97,1 mm2 seçilir. Kazanç eğrisinden (Şekil 2.2) minimum anahtarlama frekansı 85kHz olarak elde edilir.


Şekil 2.2 LLC Rezonans dönüştürücünün tipik kazanç eğrileri

[ADIM-7] Rezonans kapasitesi seçimi:

Rezonans kapasitörü seçerken, akım değeri dikkate alınmalıdır çünkü kapasitörden dikkate değer miktarda akım akar. RMS rezonans kapasitör akımı denklem 11’de verilmiştir.

Icr

Rms ≅ √[
πIo
2√2n

]

2
+ [

n(Vo+2⋅Vr

)
4√2foLm

]

2
(Denklem 11)

Ardından rezonans kapasitörünün normal çalışma şartları altında maksimum gerilimi denklem 12’de verildiği gibidir.

Vcr

max ≡

Vin

max

2

+

√2⋅Icr

RMS

2⋅π⋅f0⋅Cr

(Denklem 12)

Tasarım prosedürü için Şekil 2.3’teki akış şeması diyagramı oluşturuldu ve Tablo 2.1’deki tasarım değerleri elde edildi.


Şekil 2.3 Tasarım prosedürü için akış diyagramı

Tablo 2.1 Benzetim çalışmaları için kullanılacak değerler

Parameters | Values
E ff | %96
P in | 155 W
P out | 148.8 W
n | 4.375
R ac | 251.9 ohm
L r | 110 uH
L lkp | 57.78 uH
L lks | 2.879 uH
L m | 542.2177 uH
C r | 19.03 nF
L p | 600 uH
M min | 1.1066
M max | 1.22
Np : Ns | 36 : 8
rmscr I | 1.044 A
V maxcr | 495 V
Q | 0.302
k | 9.4

### 2.2 Benzetim Çalışmaları

Teorik sonuçlar bulduktan sonra, teorik sonuçları ve simülasyon sonuçlarını karşılaştırmak için dönüştürücünün benzetim çalışmaları gerçekleştirilmiştir. PSIM programında görülmesi gereken tipik dalga formları Şekil 2.4’te verilmiştir. Ip birincil kaçak endüktans akımıdır, Im mıknatıslama akımı Ids2 ve Vds2 ikinci MOSFET akımı ve gerilimidir ve I_d doğrultucu tarafın akımıdır. Q1 ve Q2 anahtarları için, her bir anahtar %50 doluluk oranıyla sürülmelidir. Kare dalga üreteci aşaması tam köprü veya yarım köprü tipi olarak inşa edilebilir. Bu çalışmada yarım köprü tipi olarak kullanılmıştır.

Şekil 2.4 Yarım köprü LLC rezonans dönüştürücünün tipik gerilim ve akım dalga formları

İlk olarak, LLC rezonans devresi PSIM yazılımı kullanılarak benzetim çalışmaları gerçekleştirildi (Şekil 2.5). Doluluk oranı 0,5 ve rezonans frekansı 110 kHz'dir. LLC rezonans dönüştürücüsünün ve gerekli çıktı değerlerinin optimum tasarımına ulaşmak için, anahtarlama frekansı, teorik hesaplamalara ve PSIM yazılımına dayanarak rezonans frekansının yukarısında olması gerektiği belirlenmiştir. Bu nedenle, anahtarlama frekansı 115kHz'dir. Elde edilen verimlilik %95,22'dir ve bu yumuşak anahtarlama başarıyla elde edilmiştir. MOSFET'in gerilimi ve akımı arasındaki kesişme alanı Şekil 2.6’da görüldüğü gibi çok azdır.


Şekil 2.5 LLC rezonans DC-DC dönüştürücünün PSIM tasarımı

Şekil 2.6 Yumuşak anahtarlama sağlanan MOSFET gerilimi (mavi) ve akımı (kırmızı)

PSIM Simülasyonunun çıkış değerleri Sekil 2.7’de verildiği gibi elde edilmiştir. Çıkış gerilimi 47.67V ve çıkış akımı 3.07A'dır ve bu da gerekli değerlere çok yakındır. Ayrıca birincil kaçak endüktans akımı, mıknatıslanma akımı, doğrultucu yan akımı ve MOSFET'lerin gerilim dalga formları elde edilmiştir (Şekil 2.8, Şekil 2.9 ve Şekil 2.10). Simülasyon sonuçları bu tipik dalga formlarına benzemektedir.

Şekil 2.7 LLC rezonans Dönüştürücünün çıkış gerilimi (kırmızı) ve çıkış akımı (mavi)


Şekil 2.8 Mıknatıslanma (mavi) ve birincil kaçak endüktans (kırmızı) akımı

Şekil 2.9 İkincil taraf diyot akımı (A)

Şekil 2.10 Birinci ve ikinci MOSFET gerilimi (V)

Rezonans kapasitöründen geçen RMS akımı 1.072A ve normal çalışmada rezonans kapasitörün maksimum voltajı 311.5V olarak ölçüldü (Şekil 2.11).

Şekil 2.11 Rezonans kapasitörünün akım (siyah) ve gerilim (turuncu) dalga formları


Daha sonra, sistem MATLAB Simulink üzerinde oluşturuldu ve gerekli dalga formları MATLAB Simulink'te de oluşturuldu (Şekil 2.12 ve Şekil 2.13).

Şekil 2.12 LLC rezonans DC-DC dönüştürücüsünün MATLAB Simulink tasarımı

Şekil 2.13 MATLAB Simulink tasarım dalga formları


Şekil 2.14 Yükün ve normalize anahtarlama frekansı değişiminin fonksiyonu olarak LLC rezonans dönüştürücünün tipik dc voltaj kazanımı özelliği [10].

Bu benzetim çalışmasında, Bölge 1 (Şekil 2.14) ZVS'nin çalışması için uygun bölge olarak karar verildi, bu da anahtarlama frekansının rezonans frekansından daha büyük olduğu anlamına gelir. Bu nedenle, anahtarlama frekansı 115kHz olarak seçilir (hesaplanan rezonans frekansı 110kHz ve Q = 0.302'dir). Simülasyon programında tipik yarım köprü LLC rezonant dönüştürücü dalga formları ve bu tipik dalga formlarına benzer simülasyon sonuçları elde edilmelidir. Ayrıca, uygun rezonant kapasitörü seçmek için rezonans kapasitör maksimum gerilimi ve RMS akımının benzetim çalışması sonuçları ve teorik hesaplamaya göre sonuçlar çok benzer, bu da teorik hesapların benzetim çalışması sonuçlarına karşılık geldiği anlamına gelir. Yumuşak anahtarlama başarılı bir şekilde elde edilmiştir. Son olarak, Şekil 2.7’deki çıkış gerilimi ve çıkış akımı, teorik değerlere (48V / 3.1A) çok yakın olan 47.67V ve 3.07A'dır. Buna ek olarak, MATLAB Simulink tarafından LLC'nin rezonans dönüştürücüsünün simülasyonu, hesaplamanın doğru olduğundan ve sonuçların neredeyse aynı olduğundan emin olmak için benzer sonuçlar elde edilmiştir.

### 2.3 Donanım Tasarımı

LLC rezonans DC-DC dönüştürücü için güç ünitesi FSFR2100XS (Şekil 2.15), kontrol ünitesi olarak TSM1011 (Şekil 2.16) seçildi.

Şekil 2.15 İkincil taraf kontrol ünitesi olmadan devrenin son versiyonu


Şekil 2.16 TSM1011 IC (İkincil taraf kontrol ünitesi)

TSM1011 (Şekil 2.17), CV (sabit voltaj) ve CC (sabit akım) modları gerektiren SMPS uygulamaları için oldukça sık kullanılan bir çözümdür. Gerilim referansı, bir operasyonel amplifikatör ile birlikte onu ideal bir gerilim kontrolörü yapar. Birkaç harici direnç ve voltaj referansı ile birleştirilen diğer operasyonel amplifikatör, akım sınırlayıcı olarak kullanılabilir [11]. Trafo için Würt Elektronik komponent trafosu kullanıldı (Şekil 2.18). Sarım oranı 35: 8 ve Giriş gerilimi 360V ila 400V, çıkış gerilimi 48V’tur [12].

Şekil 2.17 TSM1011 IC

Şekil 2.18 Trafo 760895451 ve özellikleri

FSFR-XS serisi (Şekil 2.19), yüksek verimli yarım köprü rezonans dönüştürücüler için tasarlanmış oldukça entegre güç anahtarları içerir. Güvenilir ve sağlam bir rezonans dönüştürücü oluşturmak için gereken her şeyi sunan FSFR-XS serisi, üretkenliği ve performansı geliştirirken tasarımları basitleştirir. FSFR-XS serisi, güç MOSFET'lerini hızlı kurtarma tipi gövde diyotları, yüksek yan kapı sürücü devresi, doğru akım kontrollü osilatör, frekans sınır devresi, yumuşak başlatma ve yerleşik koruma fonksiyonları ile birleştirir. Yüksek taraf geçit sürücü devresi, mükemmel gürültü bağışıklığı ile istikrarlı çalışmayı garanti eden ortak mod gürültü iptal özelliğine sahiptir. MOSFET'lerin hızlı toparlanan vücut diyotu, anormal çalışma koşullarına karşı güvenilirliği arttırırken, ters toparlanmanın etkisini en aza indirir. Sıfır gerilim anahtarlama (ZVS) tekniğinin kullanılması anahtarlama kayıplarını önemli ölçüde azaltır ve verimliliği önemli ölçüde artırır. ZVS ayrıca anahtarlama gürültüsünü de önemli ölçüde azaltır, bu da küçük boyutlu bir Elektromanyetik Parazit (EMI) filtresine izin verir [13].


Şekil 2.18 FSFR-XS paket şeması

LLC rezonans DC-DC dönüştürücü kartının tasarım aşamaları Autodesk firmasının Eagle yazılım programı kullanılarak yapıldı. Gerekli elektronik bileşenler Tescom A.Ş. tarafından sağlanan tedarikçi web sitelerine (OZDISAN ve DIGIKEY) göre araştırılmıştır. Eagle üzerinde şematik ve PCB kurulu çizim için bulunan bileşenlere göre, gerekli footprint kitaplıklarının Eagle'da bulunup bulunmadığı kontrol edildi. Uygun bir kütüphane yoksa, bunların footprintleri çizilmiştir. Devre için çizilmesi gereken az sayıda footprint vardı. Örneğin, EAGLE üzerinde uygun bir footprint kütüphanesi olmadığı için TSM1011 kontrol entegresinin kapladığı alan çizilmiştir (Şekil 2.19). Daha sonra, devrenin şeması Eagle Autodesk programı üzerinden oluşturuldu (Şekil 2.20 ve Şekil 2.21)


Şekil 2.19 TSM1011 footprinti

Şekil 2.20 LLC rezonans dönüştürücünün birincil taraf şeması


Şekil 2.21 LLC rezonans dönüştürücünün ikincil taraf şeması

Şematik tamamlandıktan sonra, dönüştürücünün PCB tasarımı yapılmıştır (Şekil 2.22). PCB'nin alanı 10 cm x 10 cm olarak belirlenmiştir. Ayrıca simülasyon programında tüm akım yollarının mevcut değerleri ölçüldü. Çünkü kartın akım yolları mevcut değerlere göre kalın veya ince yapılmıştır. PCB bileşimi tamamen bir malzemeyi diğerinin üzerine sermekle ilgilidir. Levhanın en kalın, orta kısmı yalıtkan bir malzemedir. Bunun her iki tarafında elektrik sinyallerinin geçtiği ince bir bakır tabakası vardır. Bakır tabakaları yalıtmak ve korumak için, PCB rengini veren ince bir lake benzeri lehim maskesi tabakası ile kaplıdır. Son olarak, her şeyden önce, PCB'ye metin

ve logolar ekleyebilen mürekkep benzeri serigrafi katmanı eklenir. Eagle yazılımında şematik editörden PCB kartı tasarımına geçiş işlevi vardır. Şematikten eklenen tüm parçalar orada olmalı, üst üste istiflenmeli, yerleştirilmeye ve yönlendirilmeye hazır olmalıdır (Şekil 2.23).

Şekil 2.22 Alt ve üst katman bağlantıları

Şekil 2.23 LLC rezonans dönüştürücünün PCB çıktısı

PCB tasarım aşaması bittikten sonra gerber dosyası oluşturulup basım için gönderilmiştir. Kart basımı tamamlandıktan sonra gerekli elektronik malzemeler PCB’ye lehimlendi ve kart test için hazır hale getirildi (Şekil 2.24 ve Şekil 2.25)


Şekil 2.24 LLC rezonans dönüştürücünün ön kısmı


Şekil 2.25 LLC rezonans dönüştürücünün arka kısmı
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

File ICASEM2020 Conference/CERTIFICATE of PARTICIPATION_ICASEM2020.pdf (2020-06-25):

CERTIFICATE; OF PARTICIPATION Turhan Can Kargin; INTERNATIONAL CONFERENCE OF APPLIED SCIENCES, ENGINEERING AND MATHEMATICS; DATE; Prof. Dr. Andrej Stefanov; 04 June 2020

For participating at IBU ICASEM 2020 with presentation titled:
“High Power Eciency Design Approach of a LLC Resonant Converter for UPS Battery Charger Application and Battery Charge-Discharge Regression Model”


The president of the Scientific Committee

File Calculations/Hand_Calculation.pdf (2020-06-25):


: , - | _ ... "!'!-:! !: !!!:.::::::,: ı.-~a-ıı- ıı.:;• ı.l' •••••-ıı.• | ~• _.. .. --~ • - •·•- •••••- .. --.-.. ---- -----· __
~ ~<:Ac ~O'l,'Q

(\ -= ':S5: '8 ~ lt 'Y~-5 ~ 0/~ 3

! LP -= &:x:> J.A • ı - 4 o')ı il \-t + ..J. / °O

### !l Lr = iOO .u 1-i ~ o o/-::, -» U'~ı< -== i:i_Q ,uF

### i k pu ~ V.?l ~= (,ı.Q':) Vd c._

### i O.,.ı..pL.d G rr~" l:: ~-1 A J i Ll~ · ~ vJ -= ?ov. t

0uJ- pl~ t V y \\-J .a.. .:- Gi V_)

## . ~ ur T;-A,<.. (Qqu L~ \b .:: .,,.cb M_::, ( S0 ı: \(l_ froq_)

### ~c_ Lı "k- Ce>f°-c,tcx- sc J z_o µf

l

Lf ~ M -Lr ;.J. 111\ ; /\ =- j. . j_O b l::, f\ ~ 'L- \J ,,... ~ Ltro - !l..c ~ L<·b1'AAI~
2.lD~ô ~ :
' t,~~ç: ~ M x ~j_O .M f- ?~~=

p.D<.A \:; 1 M ;t\
-= 3b'.>. 21b V 1
' t ç.~ _. 0 -5b

"'" r .:- 5- l< S L ';,5 ı {V'().--1 \J

f i'(\ .:= j ~ 1,5L .1 b 7 \J 1 (\ .:::-- Lı.. o::,

\ 0-66

1

Mr,ııg.. " =- u ..) o l_L, Roc. ~ 1 Si- ~ JL.1
1

## ~ j_ - (O b o : 1 . ç ~ ""''\- -ı s ~ ne

~-..>1.b~
1
;

## Ct . u~( u~?< J,..o.~ ) i-

ı \ C....Q 0 1'J tv-: (\ - X j... {06ö = L< . u..ı p ~
! (\ = 2. ~ M,I\ l _,
2. ( c.., <g . 1,o.q) . -,... J ı< .i.!.9-0bxO· ıı~ ,L:> i

j
i
i

'
1

N MI{\

- }:."<>i, A~ -l.1.51 'd. . if ~ p ~ ~0-3 ·. Np::. t,.(J~ X ? :: 3.!, ) b
~ c..,;:.I\~~ 1-. dı3"t- ~"'llQ11)~ Nf ~ rı . lJ !, _r (d tı( Z ~ 35-alc , ho ~ l~~L (, ... ıı -.t"n.v\ •

~ ~:1
f re~ b-' ilD ~ ~-fe l ~la-ok. ~ c-i \ li

### -- ı. 2 -=- ıa- o~ (\F

(21r J<HôAc.:,") x1ro~ıs 6

f-'{ ~ ,ı' -=- t 1. 'L
ıV ::ı ı-:ı2 ı·,ı ı. -=- 0 -3 o.2.
.2" 1t :ıı. .ilD ,.. t ~:>,c 2s1.5" 13-G3~t5 ~ +
j.5

L.p .__ LM.-'- lu~.p
L r .:- LL.k-P-+ l~ / ( LL~p

<bDOµ ~ :::- LM..ı L\.p
LLlP = bOOµ H-LM

### LM 'ı( llp Lr .=; LL"--ı? + ----

LM..ı L1t..p

f)bCOQ:::.0t:,cooo-o,?6~•l""'1...~ oo ~

## LM ı. .:.2 ~4 Do:) ~ LVV\ -=:- tı 2.. ı-r:ı-

6 O O µ. µ. - S l<'l.. 2. t)1-µ H = 5 + -18 A H.:.lu . .p

# (L~1c~.,. 2-Sf 3 ,u H]

1

i a ""F .::: 6 o a )-l (.\ - LM +
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

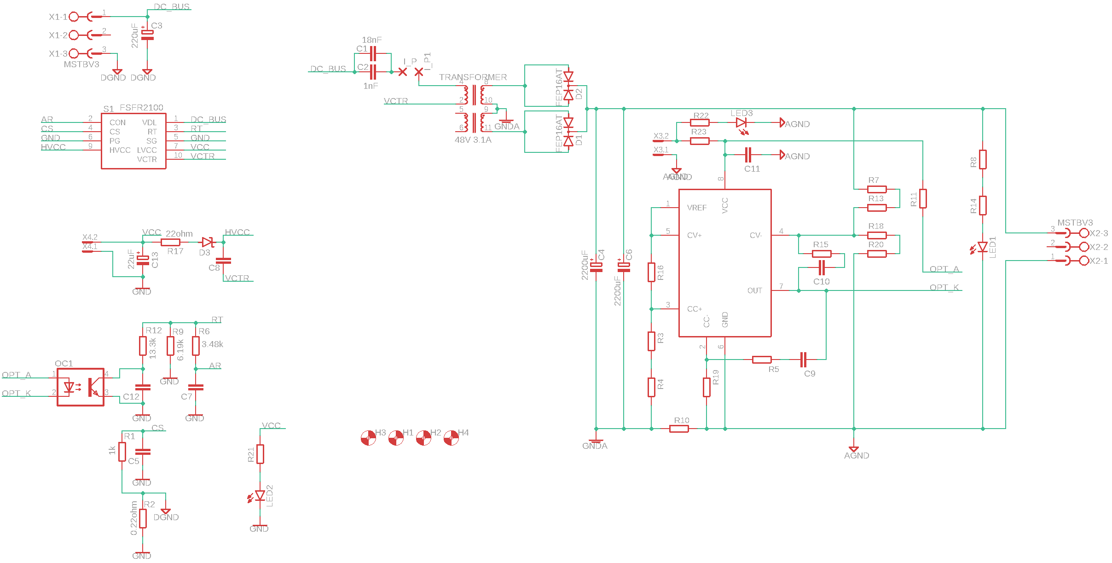
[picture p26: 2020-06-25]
PCB Design/Schematic_Image.png

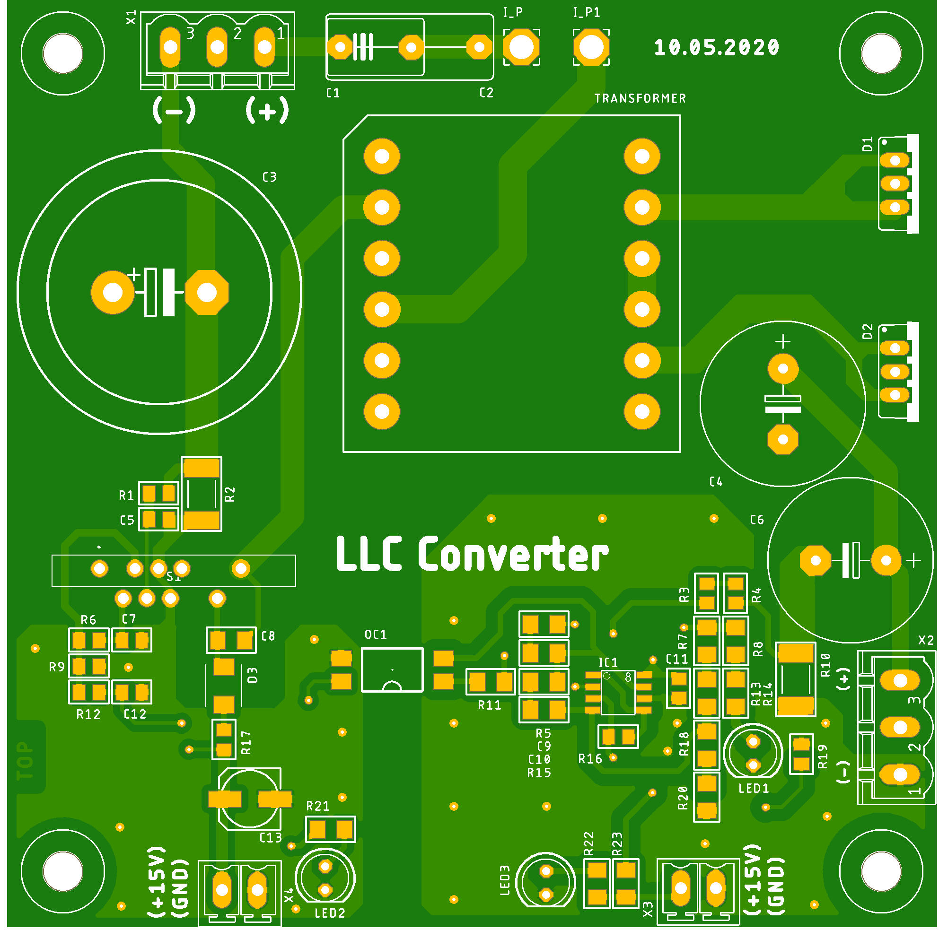
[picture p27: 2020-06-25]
PCB Design/LLC_Demo_Board_Top.png

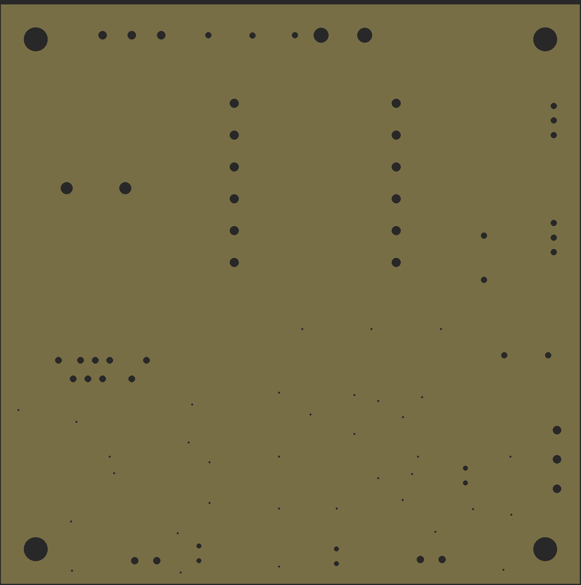
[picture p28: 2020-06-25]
PCB Design/LLC_Demo_Board_Drills.png

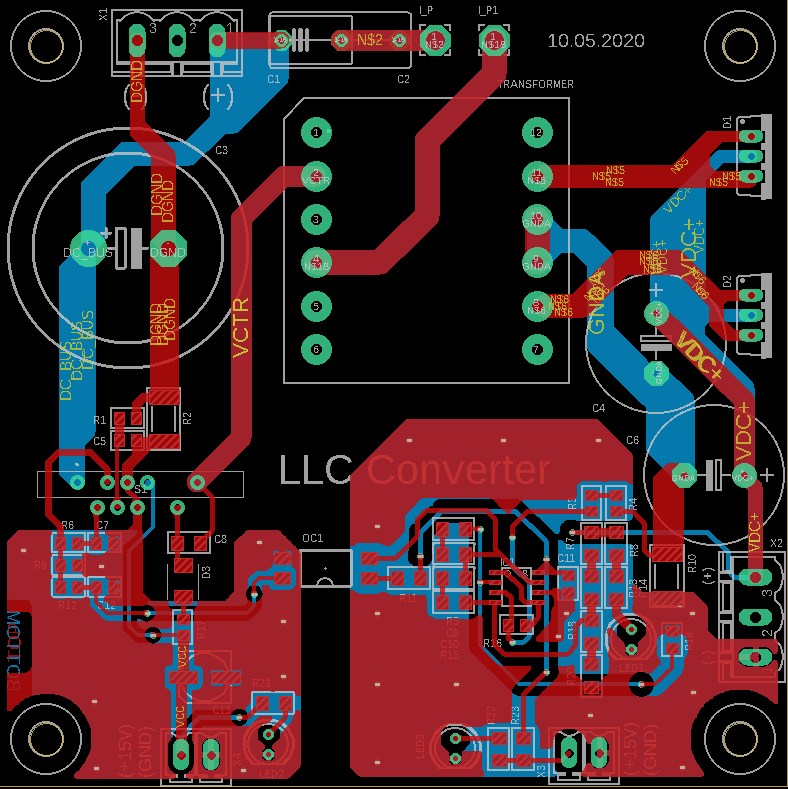
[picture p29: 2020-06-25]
PCB Design/Board_Image.png

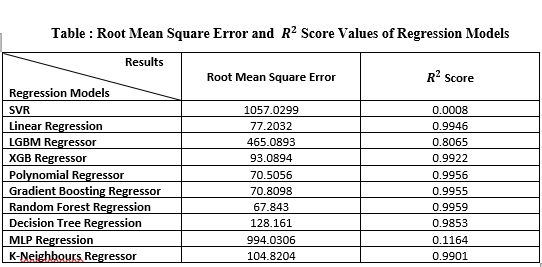
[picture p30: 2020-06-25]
Machine Learning Part/Model Comparison.PNG

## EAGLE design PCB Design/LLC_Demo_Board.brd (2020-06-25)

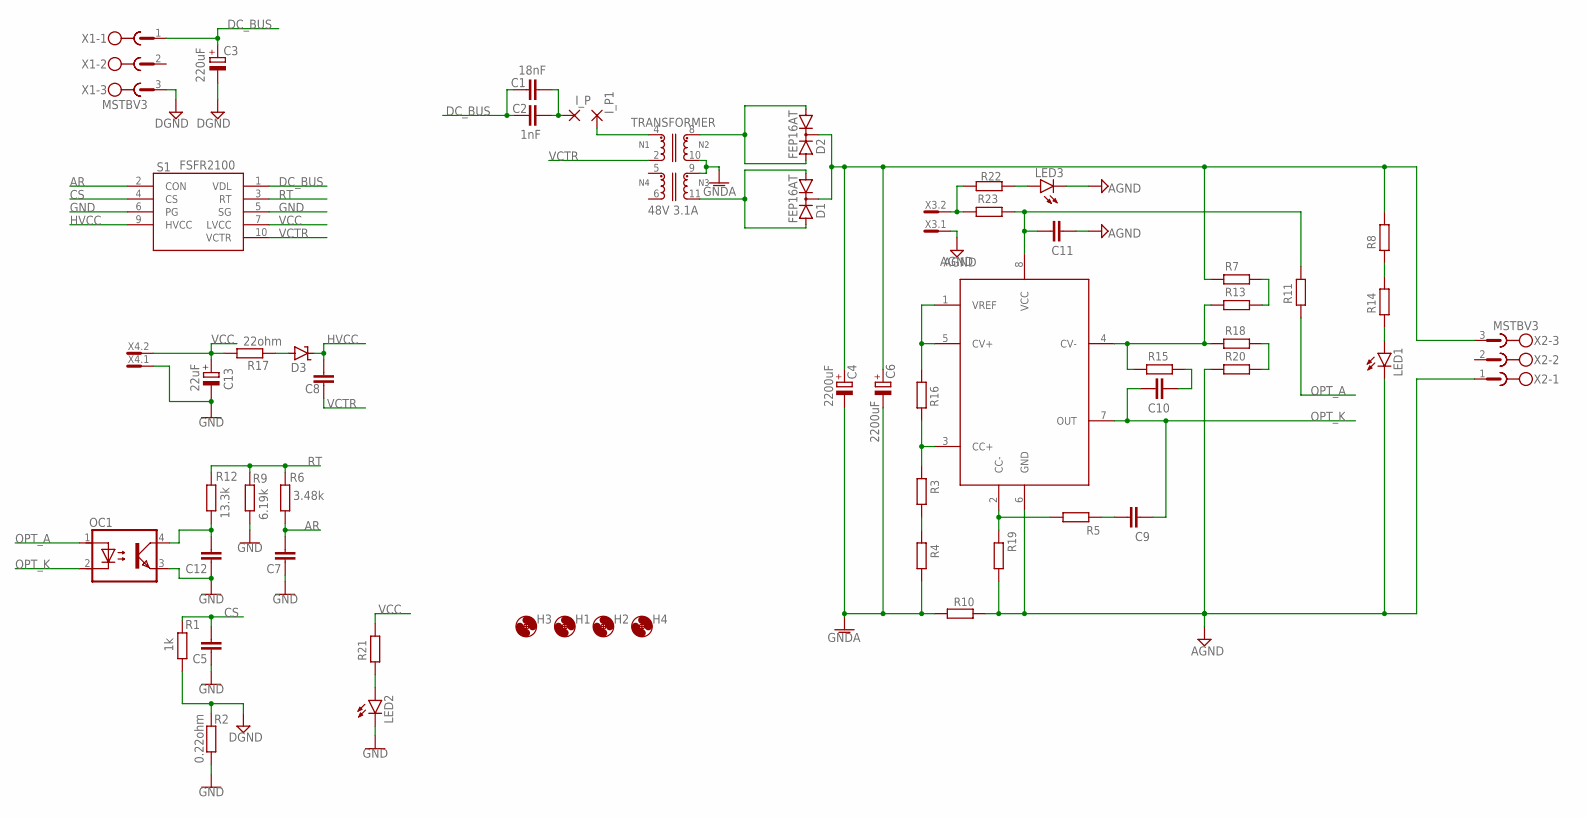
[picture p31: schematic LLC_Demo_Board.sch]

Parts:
C1: 18nF; C075-063X106
C2: 1nF; C150-072X183
C3: 220uF; EB30D
C4, C6: 2200uF; E7,5-18
C5: 100pF; C0805
C7: 220nF; C0805
C8: 150nF; C1206
C9, C10: 2.2nF; C1206
C11: 22uF; C0805
C12: 12nF; C0805
C13: 22uF; 153CLV-0605
D1, D2: FEP16AT; TO220ABS
D3: SUPPRESSOR-SMBJ; SMBJ
H1, H2, H3, H4: MOUNT-HOLE4.1; 4,1
IC1: 1039-2224 / TSM1011ID SO-8 Constant Voltage and C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; SO-8
I_P, I_P1: 3,81/1,4
LED1, LED2, LED3: LED5MM
OC1: 1039-2189 / Opto coupler CEL-Renesas PS2561DL2-1Y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; PS2561DL2-1_OPTO
R1, R19: 1k; R0805
R2: 0.22ohm; R2512
R3, R4: 500ohm; R0805
R5, R15: 22k; R1206
R6: 3.48k; R0805
R7: 180k; R1206
R8, R14, R21, R22: 1029-3175 / RES 0805 22K %1; R1206
R9: 6.19k; R0805
R10: 50m; R2512
R11: 100ohm; R1206
R12: 13.3k; R0805
R13: 12k; R1206
R16: 15k; R0805
R17: 22ohm; R0805
R18, R20: 4.99k; R1206
R23: 1k; R1206
S1: FSFR2100
TRANSFORMER: 48V 3.1A; WE-LLCR_ETD34
X1, X2: MSTBV3
X3, X4: İKİLİ MOLEX; MCV2

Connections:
AGND: C11.1, IC1.6 (GND), LED1.K (C), LED3.K (C), R10.2, R19.1, R20.2, X2.1, X3.1
AR: C7.1, R6.2, S1.2 (CON)
CS: C5.1, R1.2, S1.4 (CS)
DC_BUS: C1.1, C2.1, C3.+, S1.1 (VDL), X1.1
DGND: C3.-, R1.1, R2.2, X1.3
GND: C5.2, C7.2, C12.2, C13.-, LED2.K (C), OC1.3, R2.1, R9.2, S1.5 (SG), S1.6 (PG), X4.1
GNDA: C4.-, C6.-, R4.1, R10.1, TRANSFORMER.9 (6), TRANSFORMER.10 (7)
HVCC: C8.1, D3.C, S1.9 (HVCC)
unnamed: R22.1, R23.2, X3.2
unnamed: C1.2, C2.2, I_P.1
unnamed: R8.2, R14.1
unnamed: D3.A, R17.1
unnamed: D1.A1, D1.A2, TRANSFORMER.11 (5)
unnamed: D2.A1, D2.A2, TRANSFORMER.8
unnamed: C12.1, OC1.4, R12.2
unnamed: LED2.A, R21.2
unnamed: LED1.A, R14.2
unnamed: LED3.A, R22.2
unnamed: I_P1.1, TRANSFORMER.4 (1)
unnamed: IC1.1 (VREF), IC1.5 (CV+), R16.2
unnamed: C9.2, R5.2
unnamed: C10.2, R15.2
unnamed: IC1.4 (CV-), R13.2, R15.1, R18.2
unnamed: IC1.2 (CC-), R5.1, R19.2
unnamed: IC1.3 (CC+), R3.2, R16.1
unnamed: C11.2, IC1.8 (VCC), R11.1, R23.1
unnamed: R18.1, R20.1
unnamed: R7.1, R13.1
unnamed: R3.1, R4.2
OPT_A: OC1.1, R11.2
OPT_K: C9.1, C10.1, IC1.7 (OUT), OC1.2
RT: R6.1, R9.1, R12.1, S1.3 (RT)
VCC: C13.+, R17.2, R21.1, S1.7 (LVCC), X4.2
VCTR: C8.2, S1.10 (VCTR), TRANSFORMER.2
VDC+: C4.+, C6.+, D1.C, D2.C, R7.2, R8.1, X2.3

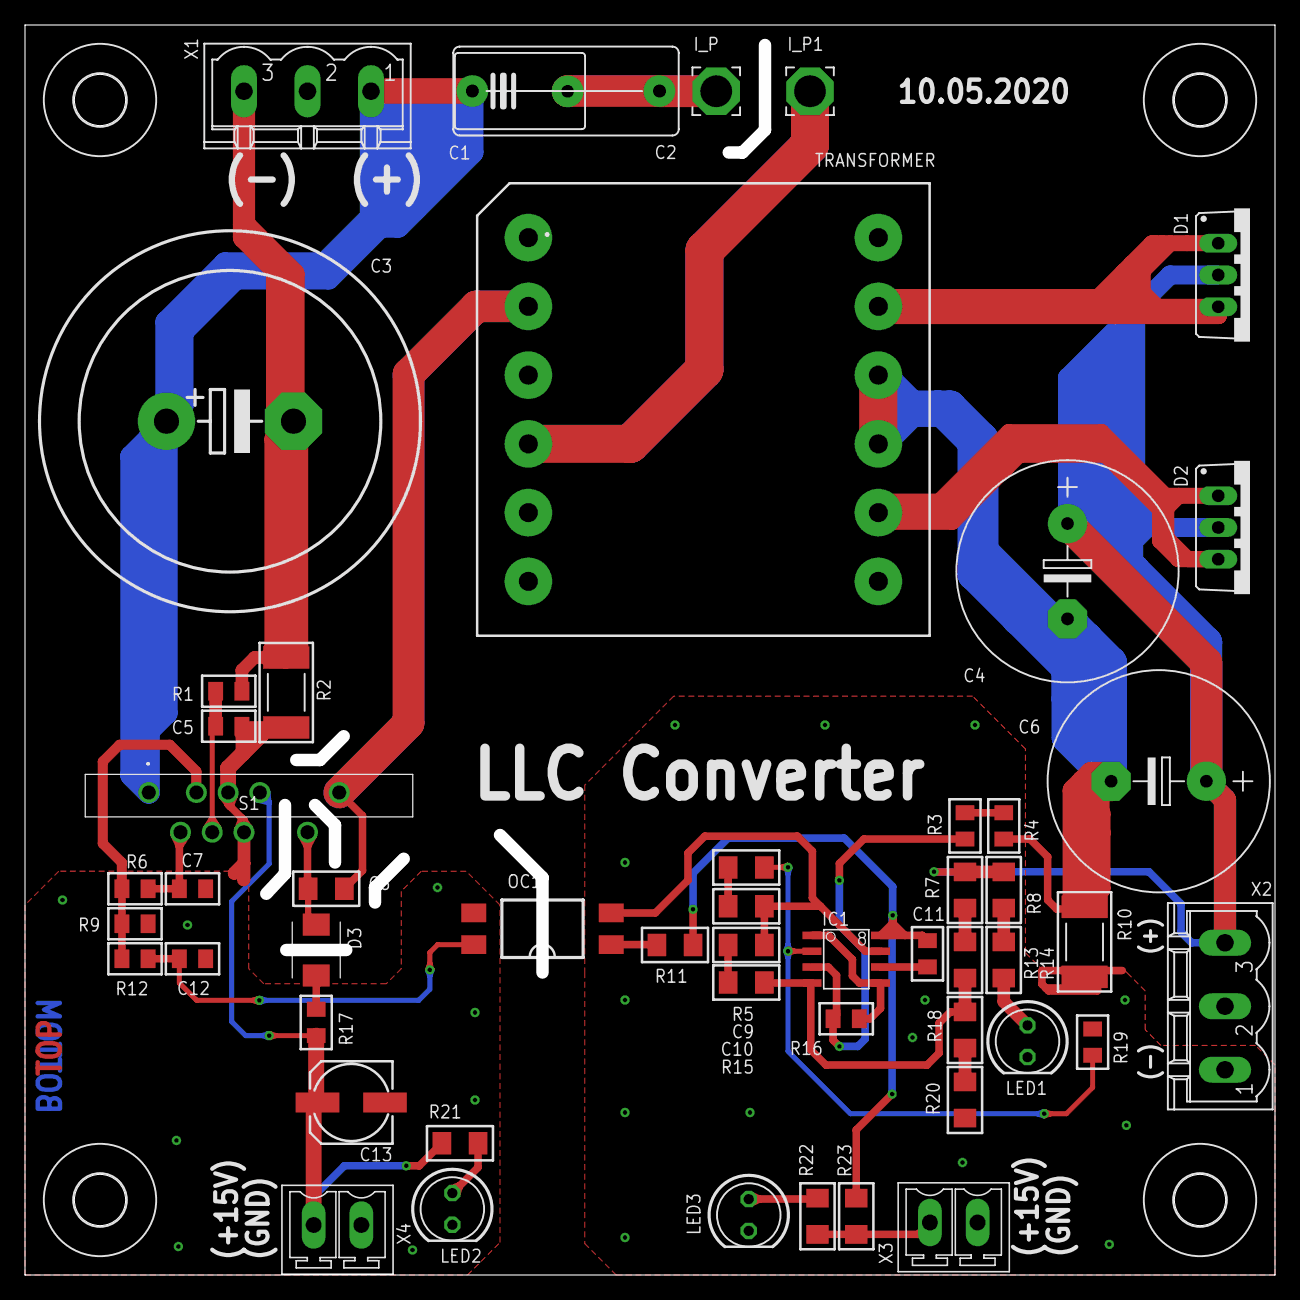
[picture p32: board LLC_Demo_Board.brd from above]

Board: 2 copper layers, 100.0 x 100.0 mm, 56 parts (0 on the bottom side), 35 nets.

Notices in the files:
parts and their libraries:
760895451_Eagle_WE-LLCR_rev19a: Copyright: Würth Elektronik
